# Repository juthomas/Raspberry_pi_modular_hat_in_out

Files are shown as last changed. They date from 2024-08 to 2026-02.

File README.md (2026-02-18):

# Raspberry Pi hat with inputs and outputs for modular synthesizer 

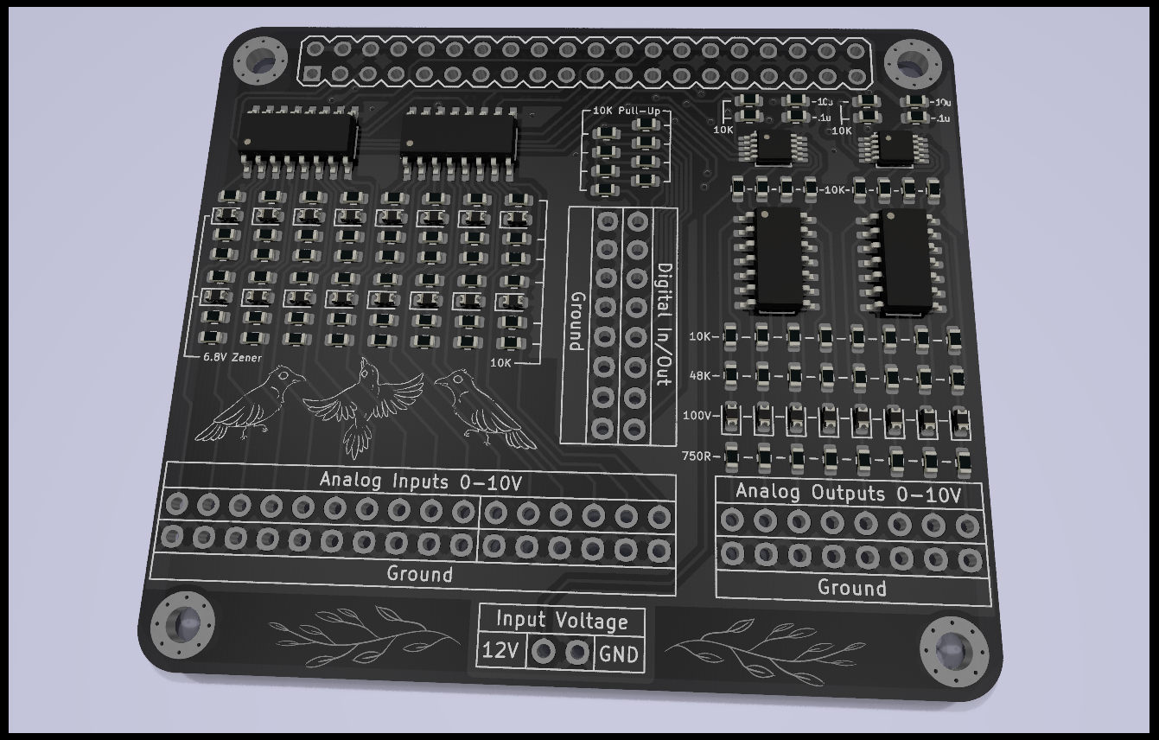
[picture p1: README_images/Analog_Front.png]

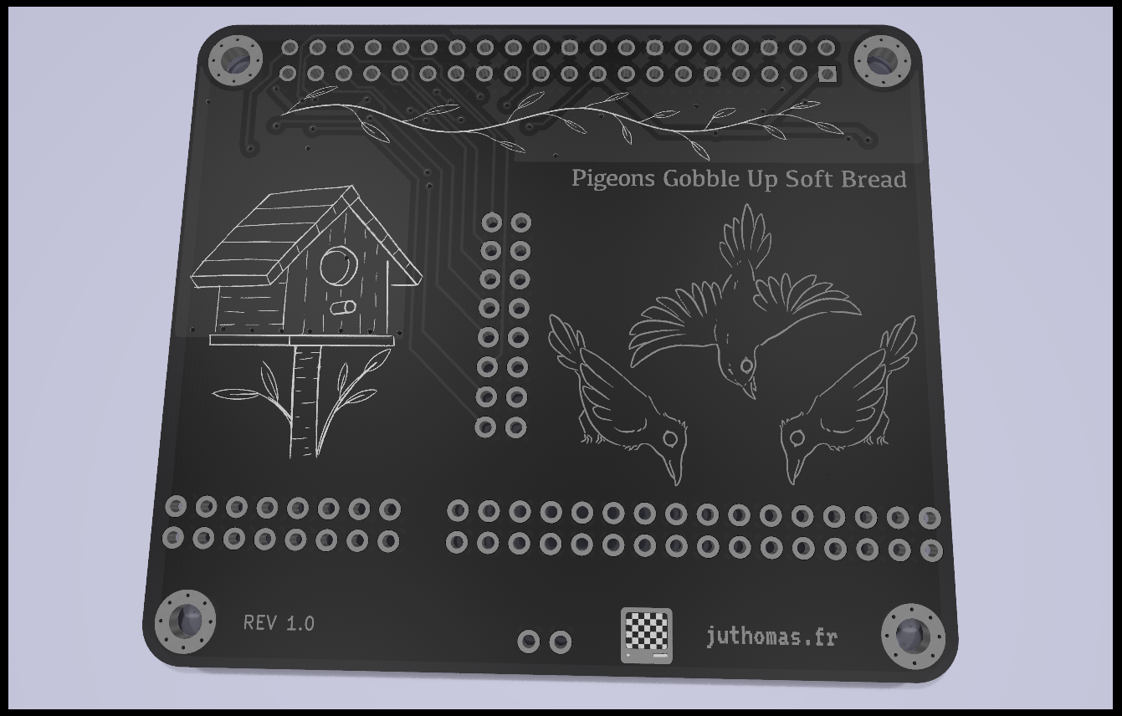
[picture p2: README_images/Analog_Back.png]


## Schematics

- [Link to pdf](https://github.com/juthomas/Raspberry_pi_modular_hat_in_out/blob/master/Schematics%20PDF/Modular_hat_in_out.pdf)

## Bill Of Materials

- [Link to IBOM](https://juthomas.github.io/Raspberry_pi_modular_hat_in_out/)

## Components

- [MCP3008](https://www.lcsc.com/product-detail/Analog-To-Digital-Converters-ADCs_Microchip-Tech-MCP3008-I-SL_C1520159.html) C1520159

- [LM324](https://www.lcsc.com/product-detail/Operational-Amplifier_STMicroelectronics-LM324DT_C71035.html) C71035

- [MCP4728](https://www.lcsc.com/product-detail/Digital-To-Analog-Converters-DACs_Microchip-Tech-MCP4728-E-UN_C108207.html) C108207

## C code examples (clean naming)

- Input reader: `C_code_example/inputs/src/input_reader.c`
  - binary name: `input_reader`
- Output generator: `C_code_example/outputs/src/output_generator.c`
  - binary name: `output_generator`
- Input/Output loopback tester: `C_code_example/input_outputs/src/input_output_tester.c`
  - binary name: `input_output_tester`

## Install dependencies and configure I2C (recommended)

Use the setup script:

`sudo ./scripts/install_rpi_dependencies.sh --baudrate 1000000`

What it does:

- installs apt dependencies (`build-essential`, `cmake`, `git`, `pkg-config`, `libgpiod-dev`, `i2c-tools`)
- installs [spidev-lib](https://github.com/juthomas/spidev-lib) in `/usr/local`
- sets `dtparam=i2c_arm=on,i2c_arm_baudrate=1000000`
- ensures `dtparam=spi=on`
- keeps a backup of `config.txt` before editing

Reboot is required after running the script.

### Manual install (if needed)

`sudo apt install build-essential cmake git pkg-config libgpiod-dev i2c-tools`

`git clone https://github.com/juthomas/spidev-lib.git`

`cd spidev-lib && mkdir -p build && cd build && cmake .. && make -j$(nproc) && sudo make install`

Do not forget to link with `-lspidev-lib` when compiling C code.

## Shell autocompletion for CLI options

The repository includes completion scripts for:

- `output_generator`
- `input_output_tester`
- `install_rpi_dependencies.sh`

Zsh (current session):

`source scripts/completions/rpi_hat_tools.zsh`

Zsh (persistent):

`echo 'source /absolute/path/to/Raspberry_pi_modular_hat_in_out/scripts/completions/rpi_hat_tools.zsh' >> ~/.zshrc`

Bash (current session):

`source scripts/completions/rpi_hat_tools.bash`

Bash (persistent):

`echo 'source /absolute/path/to/Raspberry_pi_modular_hat_in_out/scripts/completions/rpi_hat_tools.bash' >> ~/.bashrc`

## Build and run

Input side (ADC):

`cd C_code_example/inputs && make && ./input_reader`

With runtime options:

`cd C_code_example/inputs && make && ./input_reader --delay-us=100000`

Dashboard cadence is controlled in source with `EQUALIZER_EVERY` and `HISTORY_EVERY` in `C_code_example/inputs/src/input_reader.c`.

Output side (MCP4728):

`cd C_code_example/outputs && make && ./output_generator`

With runtime options:

`cd C_code_example/outputs && make && ./output_generator --resolution=1000 --delay-us=1`

Dashboard cadence is controlled in source with `EQUALIZER_EVERY` and `HISTORY_EVERY` in `C_code_example/outputs/src/output_generator.c`.

Input/Output combined test (MCP4728 sine with per-channel phase + ADS monitoring):

`cd C_code_example/input_outputs && make && ./input_output_tester --resolution=1000 --delay-us=1`

Dashboard cadence is controlled in source with `EQUALIZER_EVERY` and `HISTORY_EVERY` in `C_code_example/input_outputs/src/input_output_tester.c`.

## Electrical Voltage dividers & multiplier

### Divider
https://tinyurl.com/24boqd2k

### Multiplier
<!-- https://tinyurl.com/27d8ra9q -->
https://tinyurl.com/2aczbd22

https://github.com/WiringPi/WiringPi

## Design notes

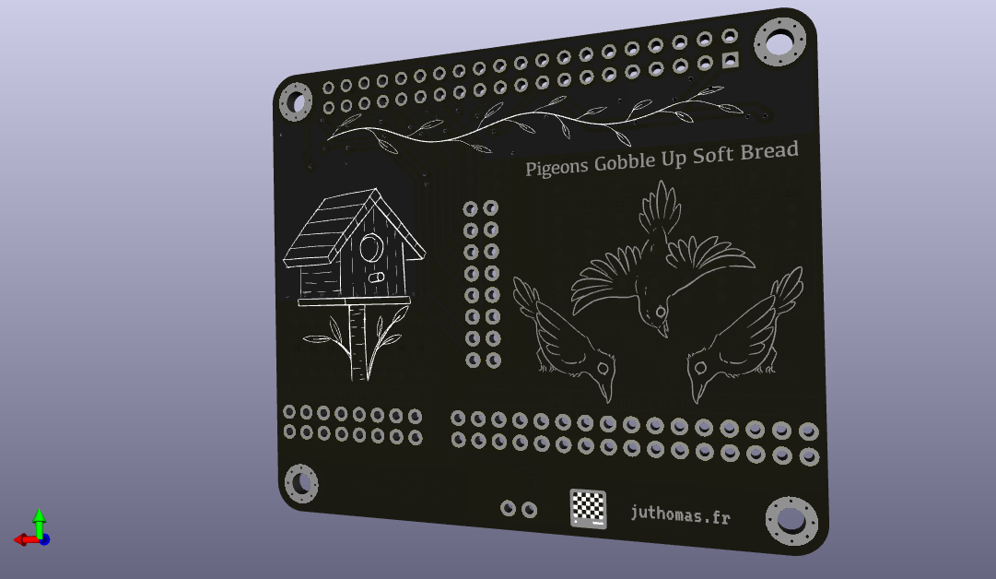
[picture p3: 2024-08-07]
Modular_hat_in_out_kicad/Modular_hat_in_out.png

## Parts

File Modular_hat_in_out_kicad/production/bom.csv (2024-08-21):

Designator | Footprint | Quantity | Value | LCSC Part #
C1, C3 | 0603 | 2 | 0.1uF | C14663
C2, C4 | 0603 | 2 | 10uF | C1691
D1, D10, D11, D12, D13, D14, D15, D16, D2, D3, D4, D5, D6, D7, D8, D9 | 0603 | 16 | D_Zener 6.8V | C2832575
D17, D18, D19, D20, D21, D22, D23, D24 | 0603 | 8 | 300mA 100V | C727112
R1, R10, R11, R12, R13, R14, R15, R16, R17, R18, R19, R2, R20, R21, R22, R23, R24, R25, R26, R27, R28, R29, R3, R30, R31, R32, R33, R34, R35, R36, R37, R38, R39, R4, R40, R41, R42, R43, R44, R45, R46, R47, R48, R49, R5, R50, R51, R52, R53, R54, R55, R56, R57, R58, R6, R61, R62, R64, R65, R67, R68, R7, R73, R74, R75, R77, R78, R79, R8, R80, R82, R84, R85, R86, R87, R9 | 0603 | 76 | 10K | C25804
R59, R60, R63, R66, R76, R81, R83, R88 | 0603 | 8 | 43K | C23172
R69, R70, R71, R72, R89, R90, R91, R92 | 0603 | 8 | 750R | C23241
U1, U3 | MCP3008 SOIC16 | 2 | MCP3008 | C1520159
U2, U6 | LM324 SOIC14 | 2 | LM324 | C71035
U4, U5 | MCP4728 MSOP10 | 2 | MCP4728 | C108207

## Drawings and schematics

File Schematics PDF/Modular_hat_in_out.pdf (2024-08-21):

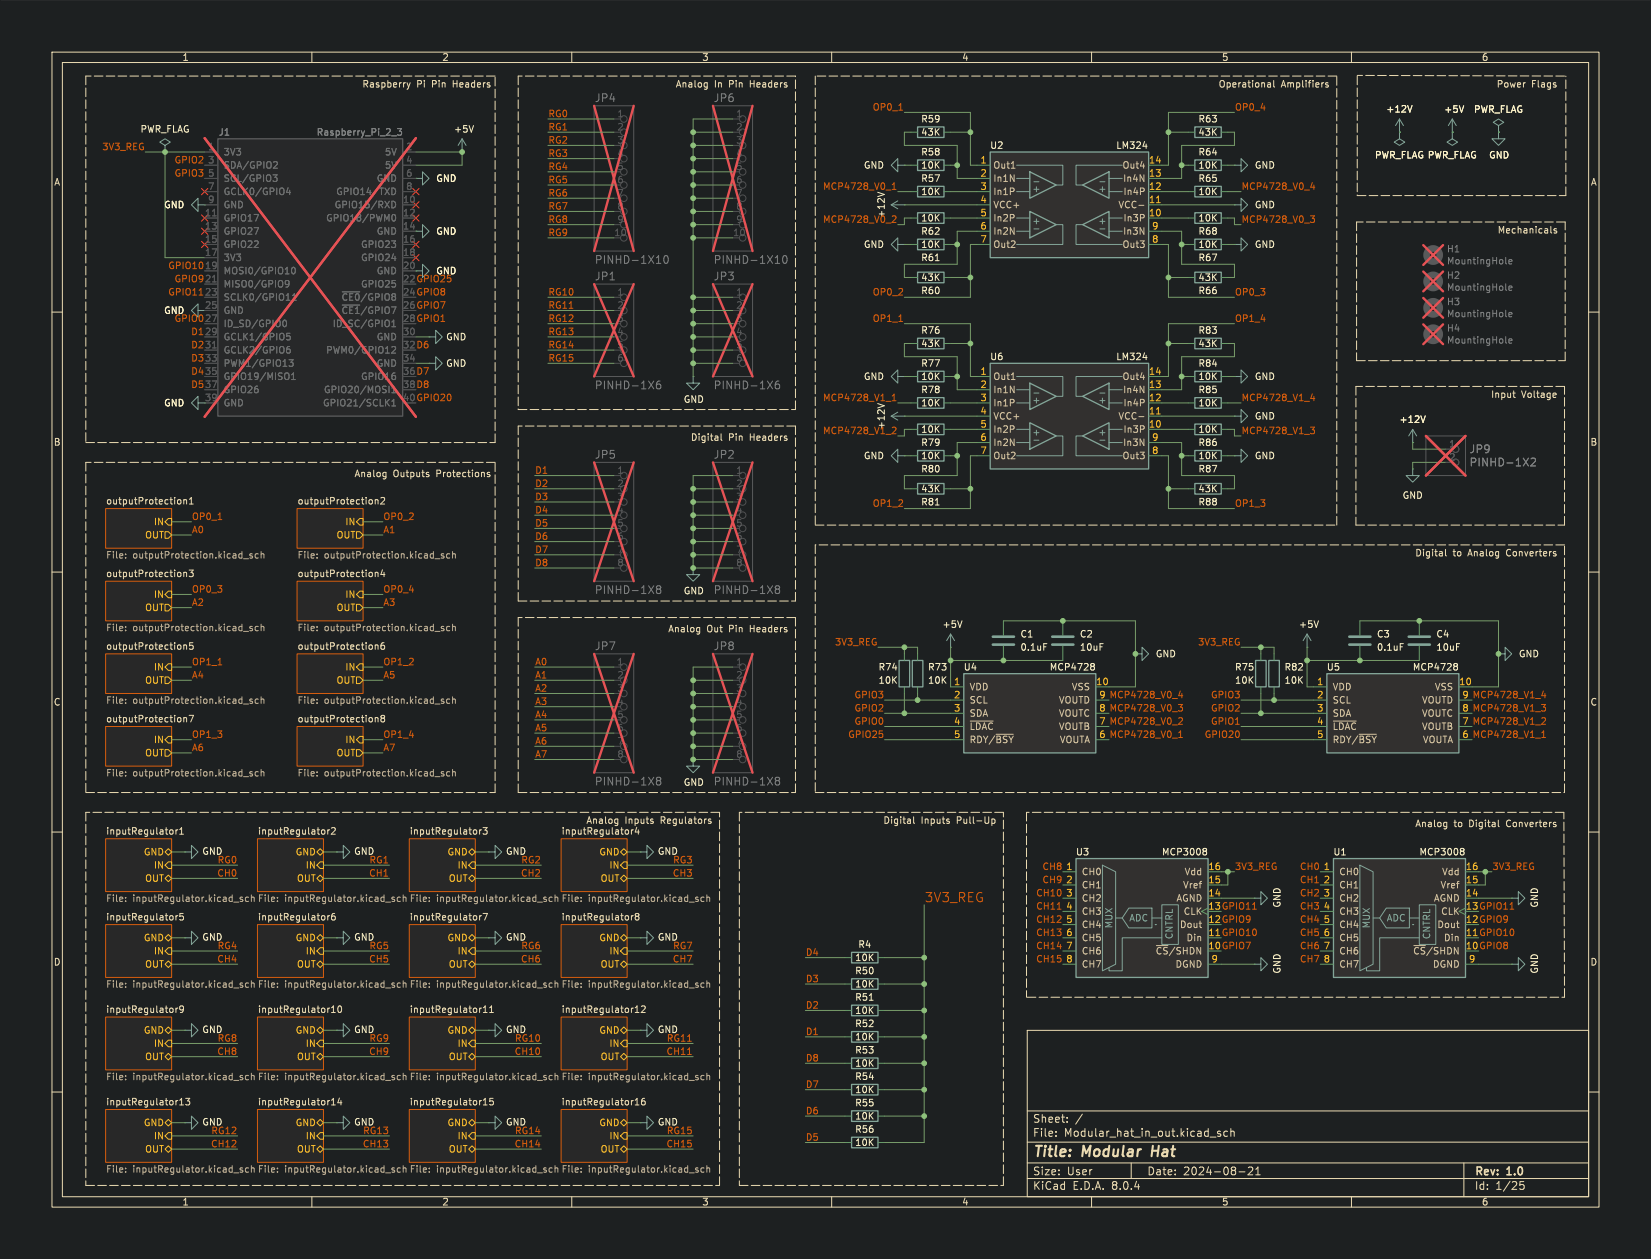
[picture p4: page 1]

Digital Inputs Pull-Up

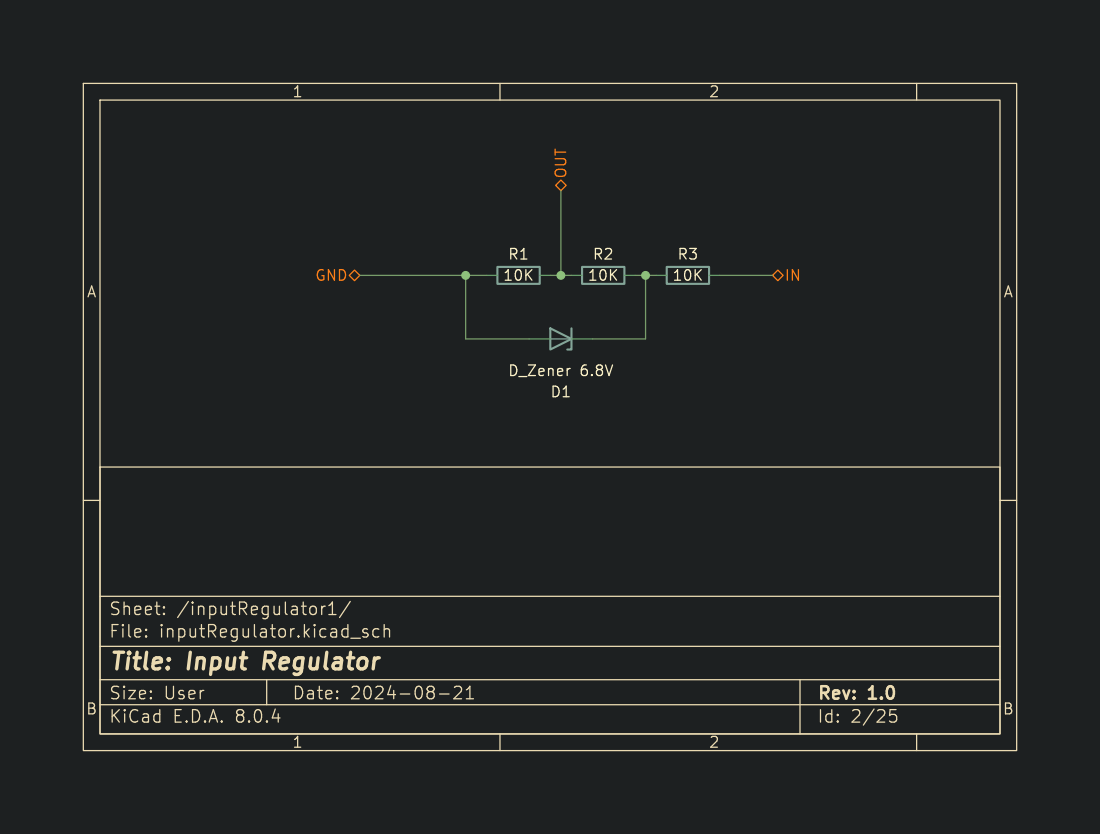
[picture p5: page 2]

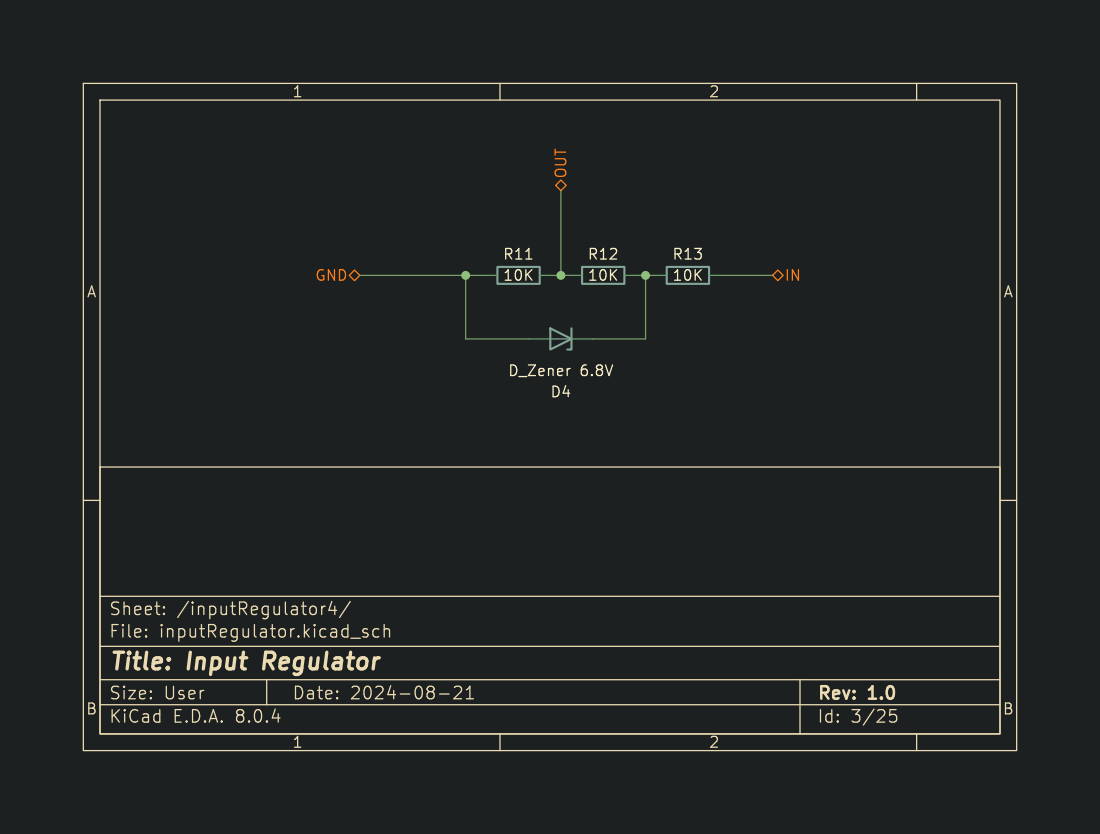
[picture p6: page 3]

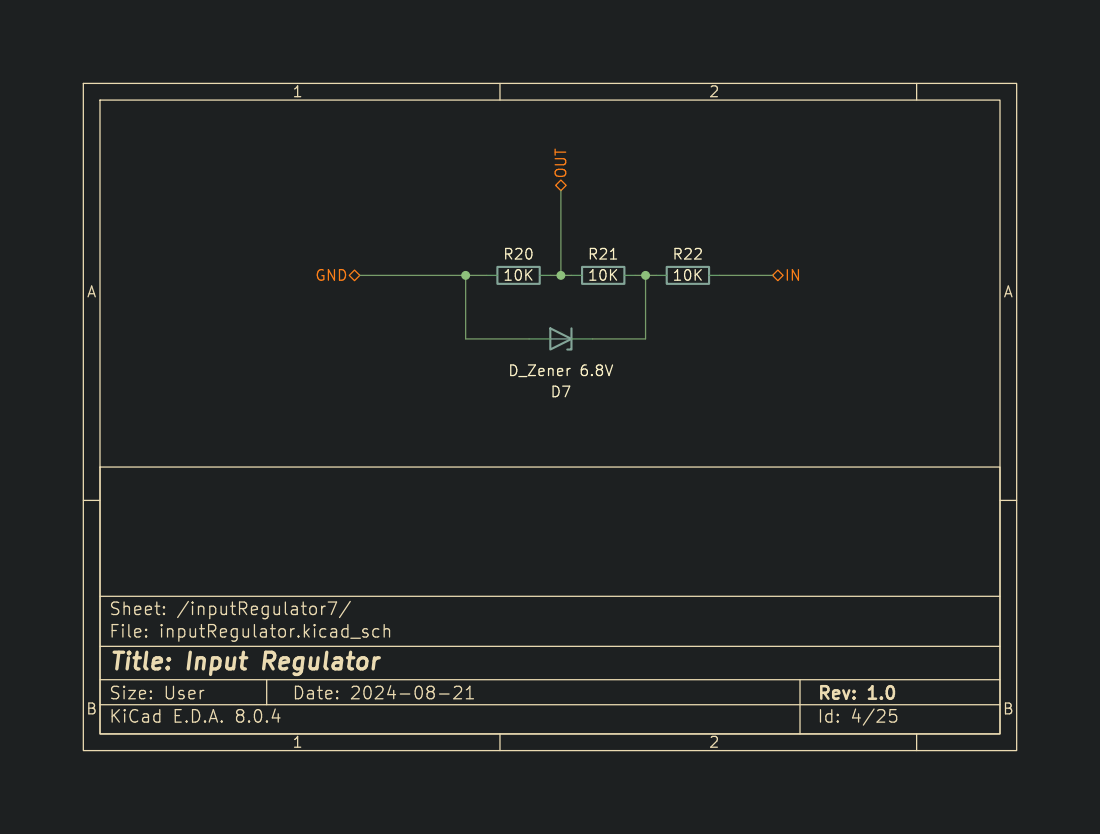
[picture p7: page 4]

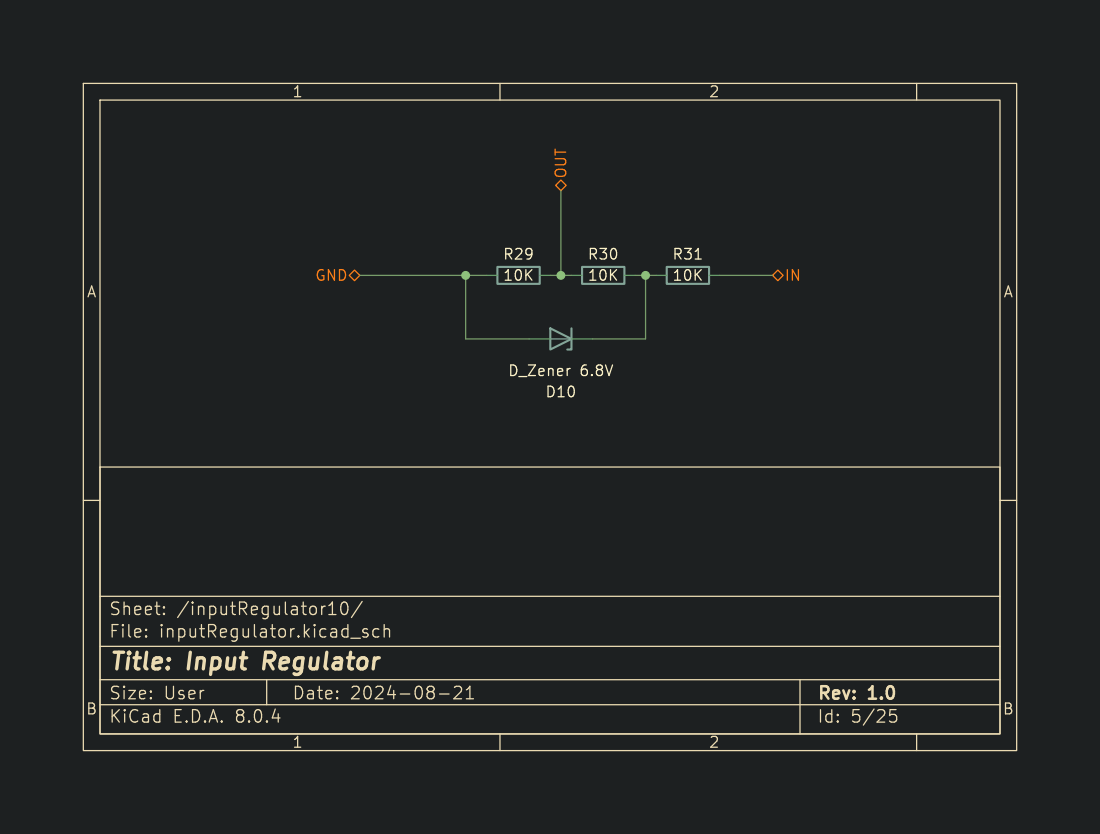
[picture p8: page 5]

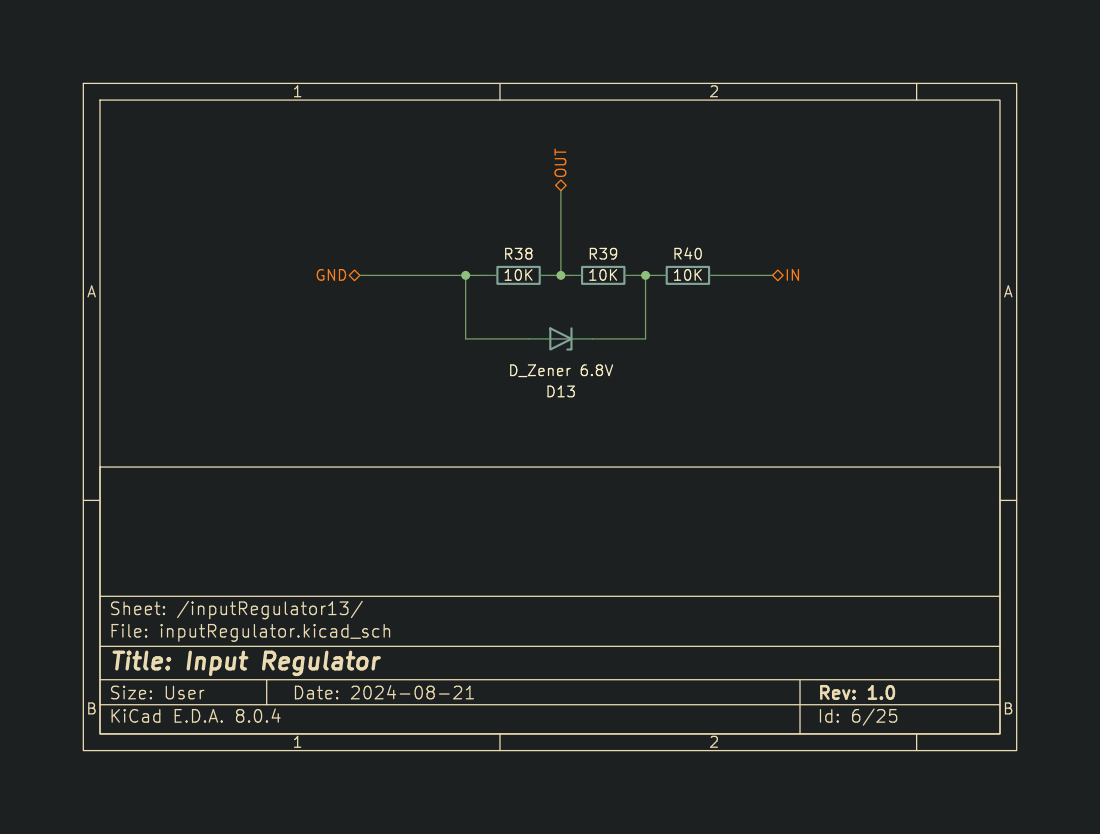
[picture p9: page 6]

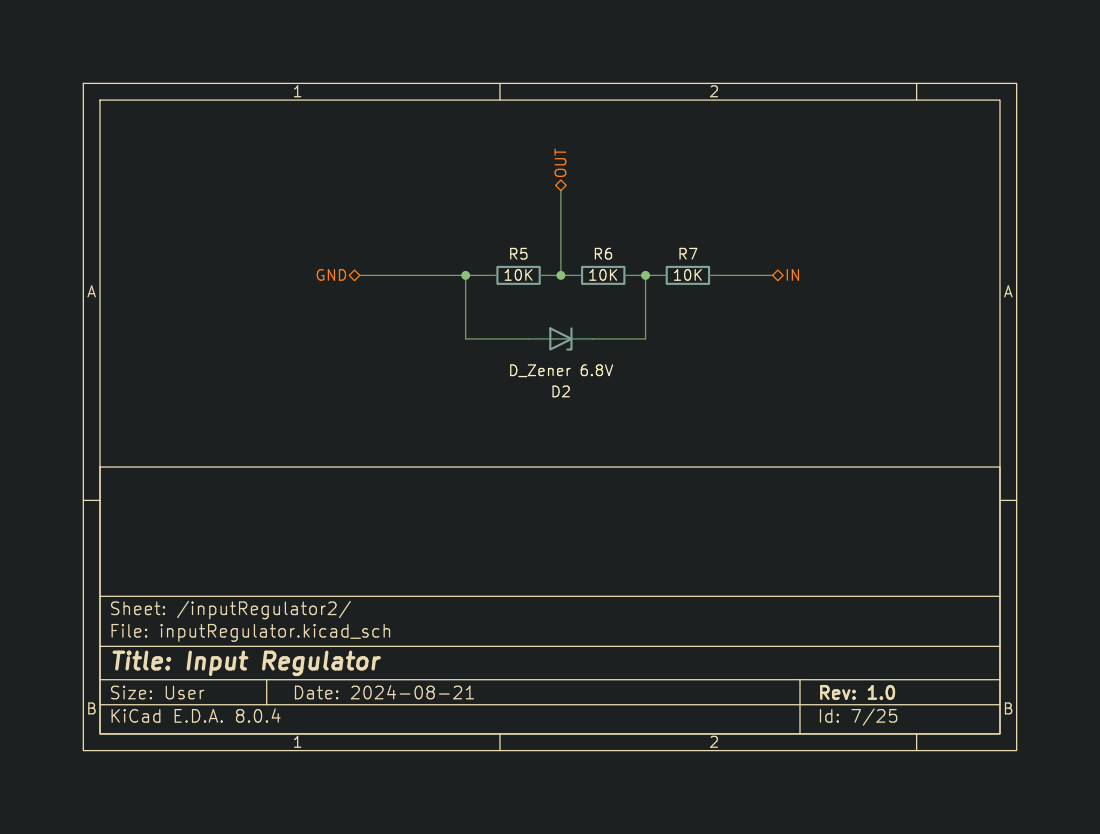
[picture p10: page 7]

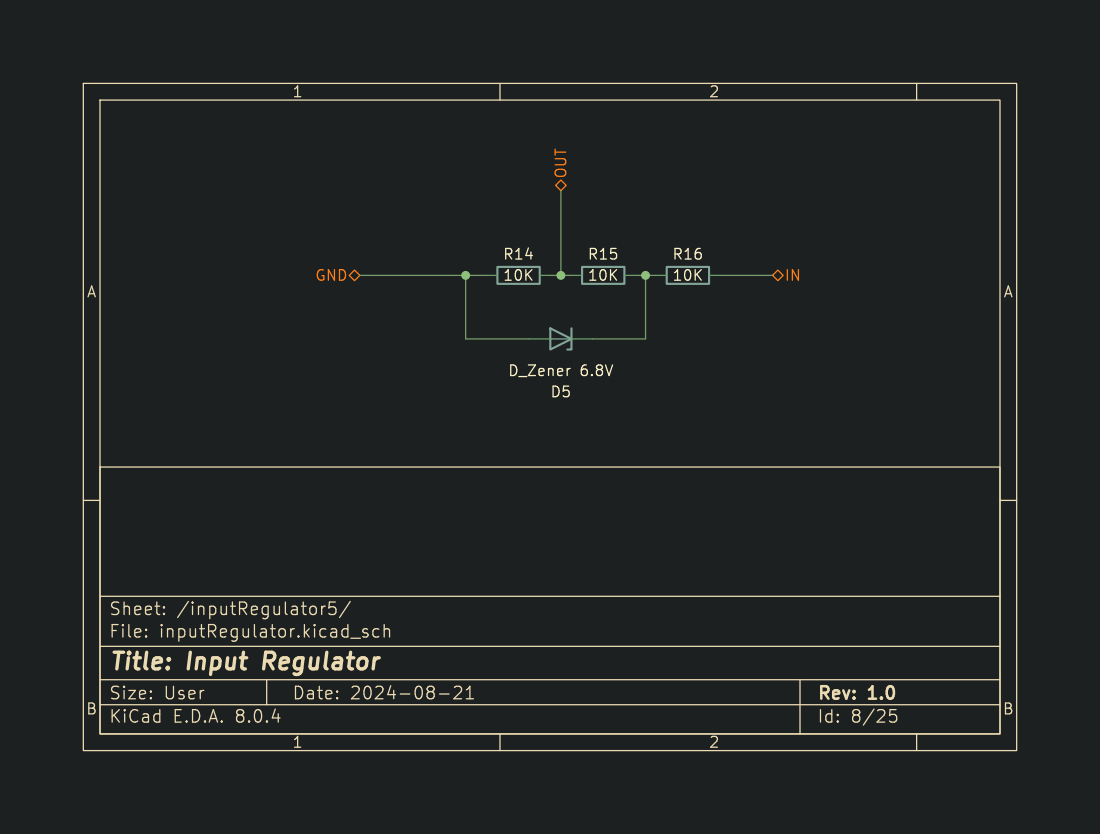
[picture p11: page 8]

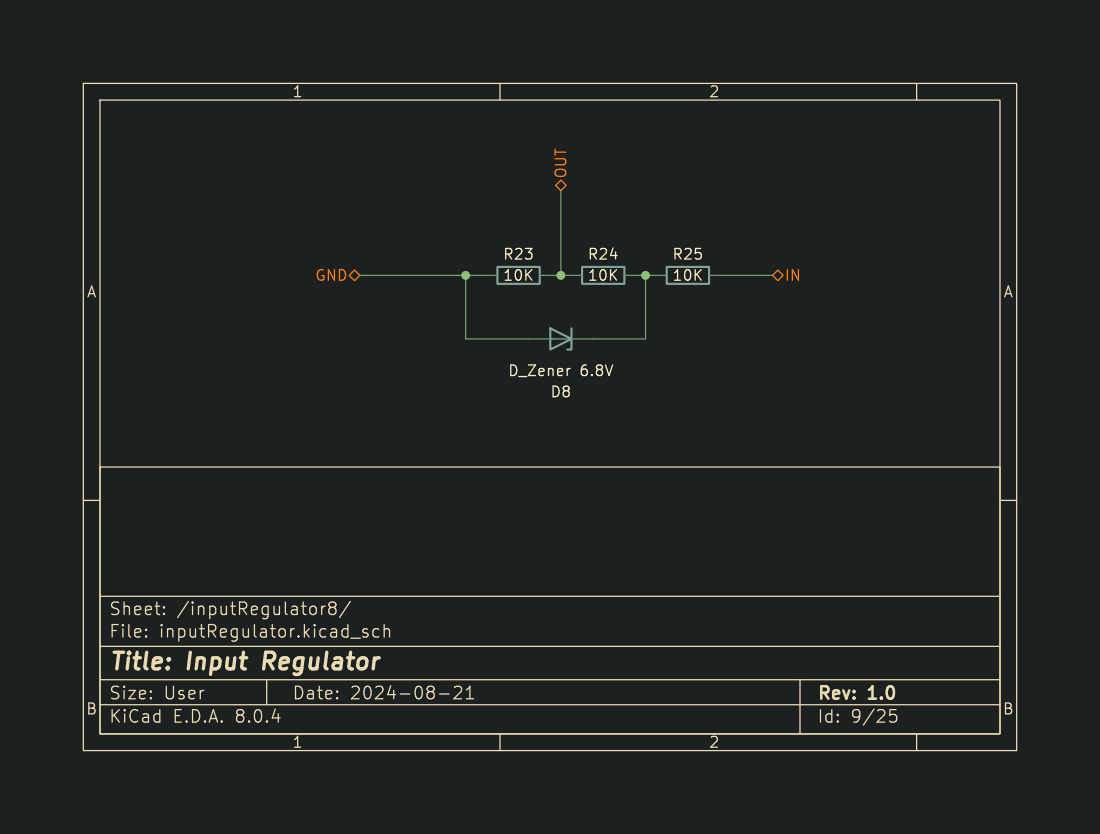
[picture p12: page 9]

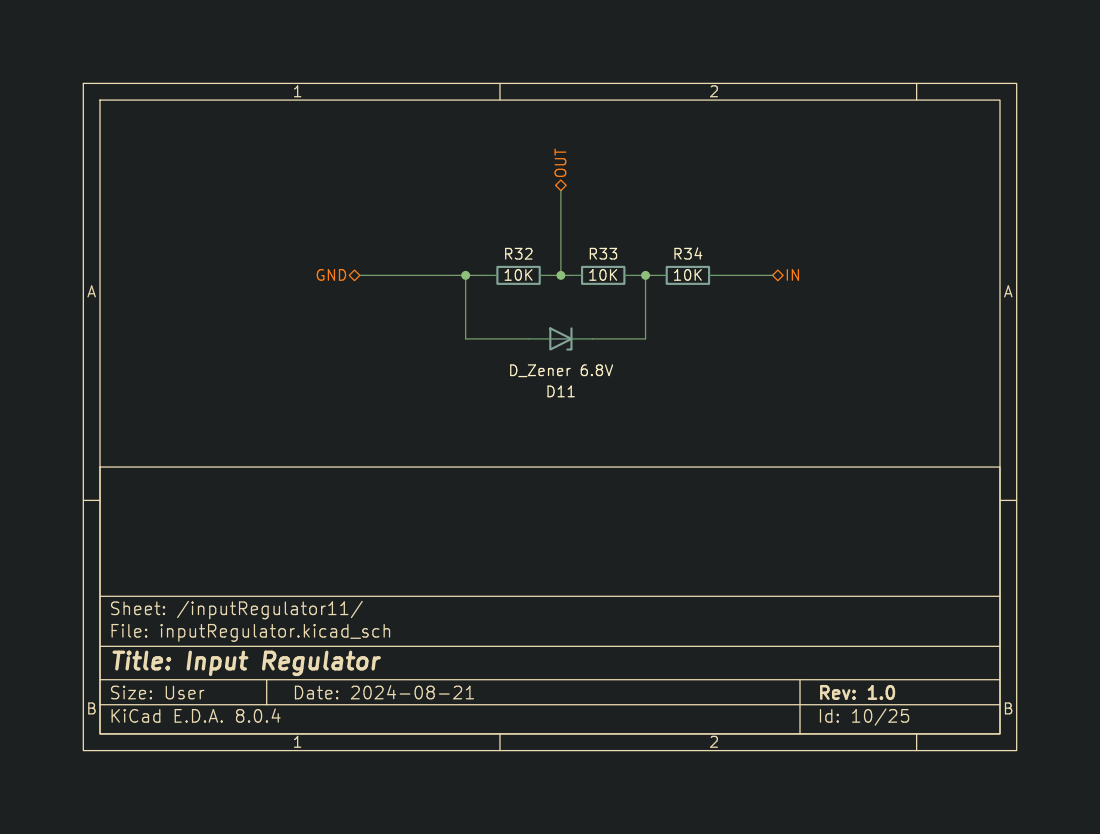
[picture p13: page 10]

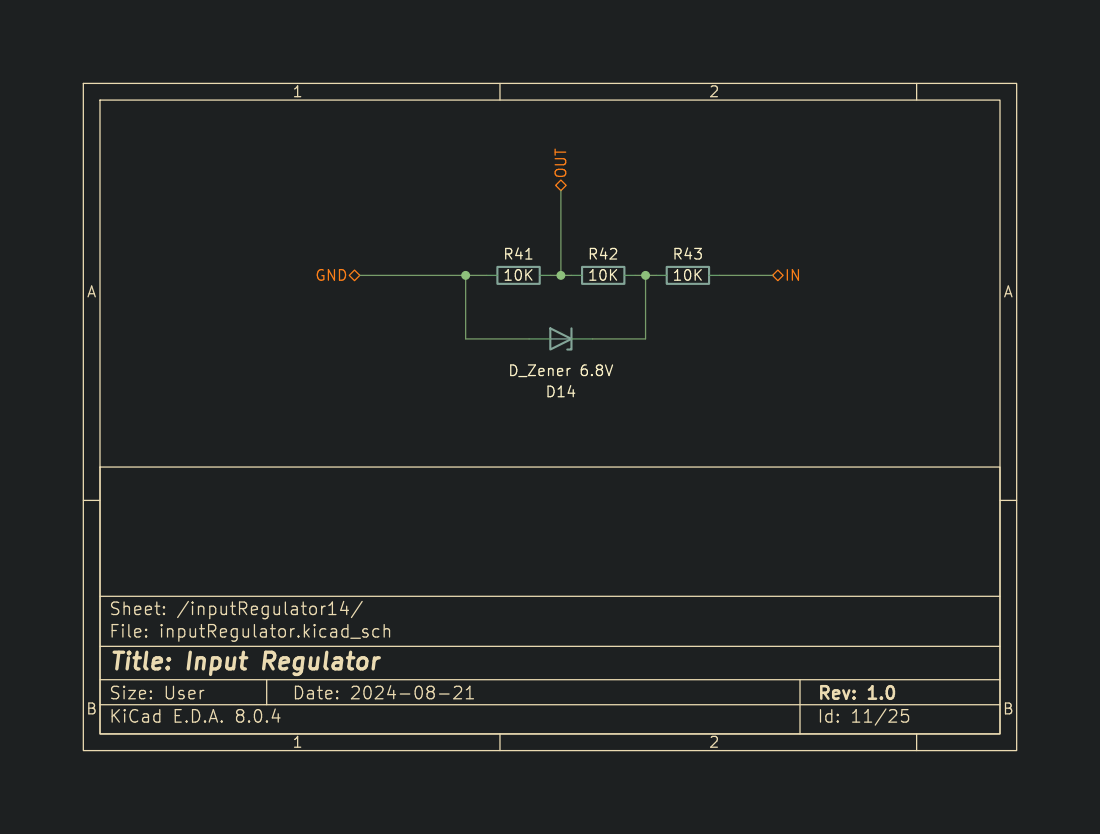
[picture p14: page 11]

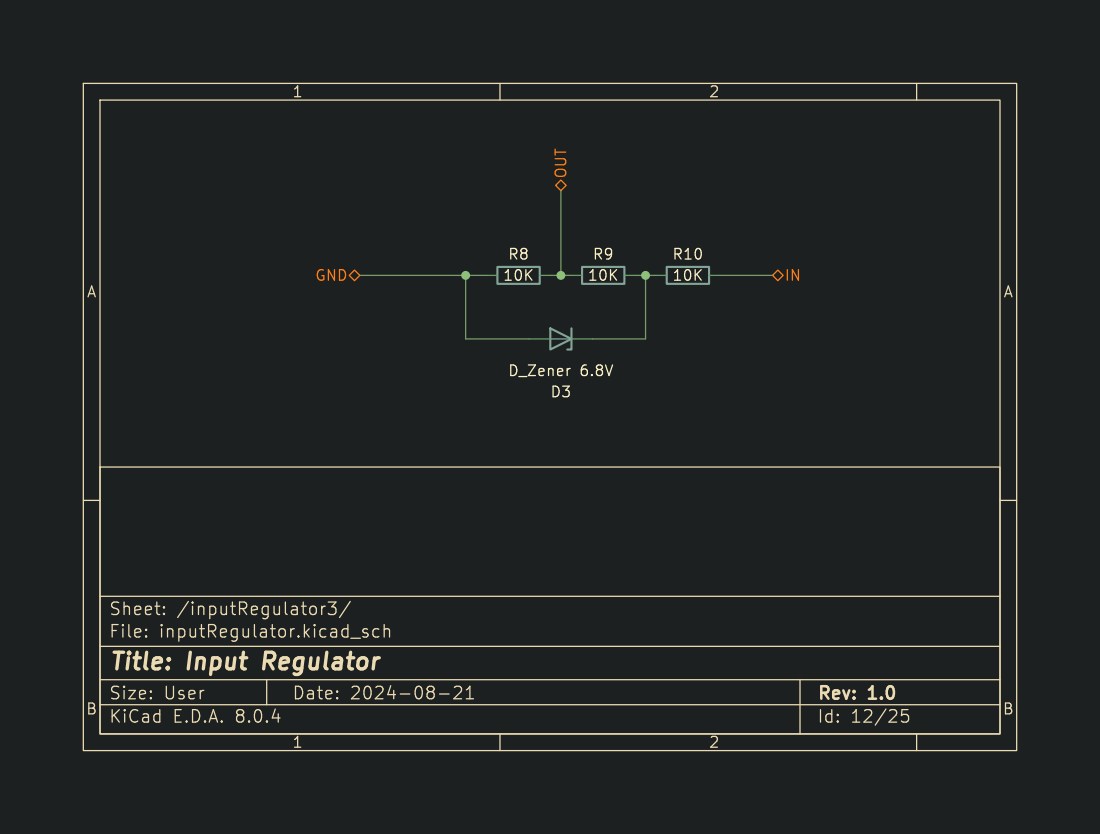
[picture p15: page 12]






Id: 18/25 Title: Output Protection


Id: 19/25 Title: Output Protection


Id: 20/25 Title: Output Protection


Id: 21/25 Title: Output Protection


Id: 22/25 Title: Output Protection


Id: 23/25 Title: Output Protection


Id: 24/25 Title: Output Protection


Id: 25/25 Title: Output Protection

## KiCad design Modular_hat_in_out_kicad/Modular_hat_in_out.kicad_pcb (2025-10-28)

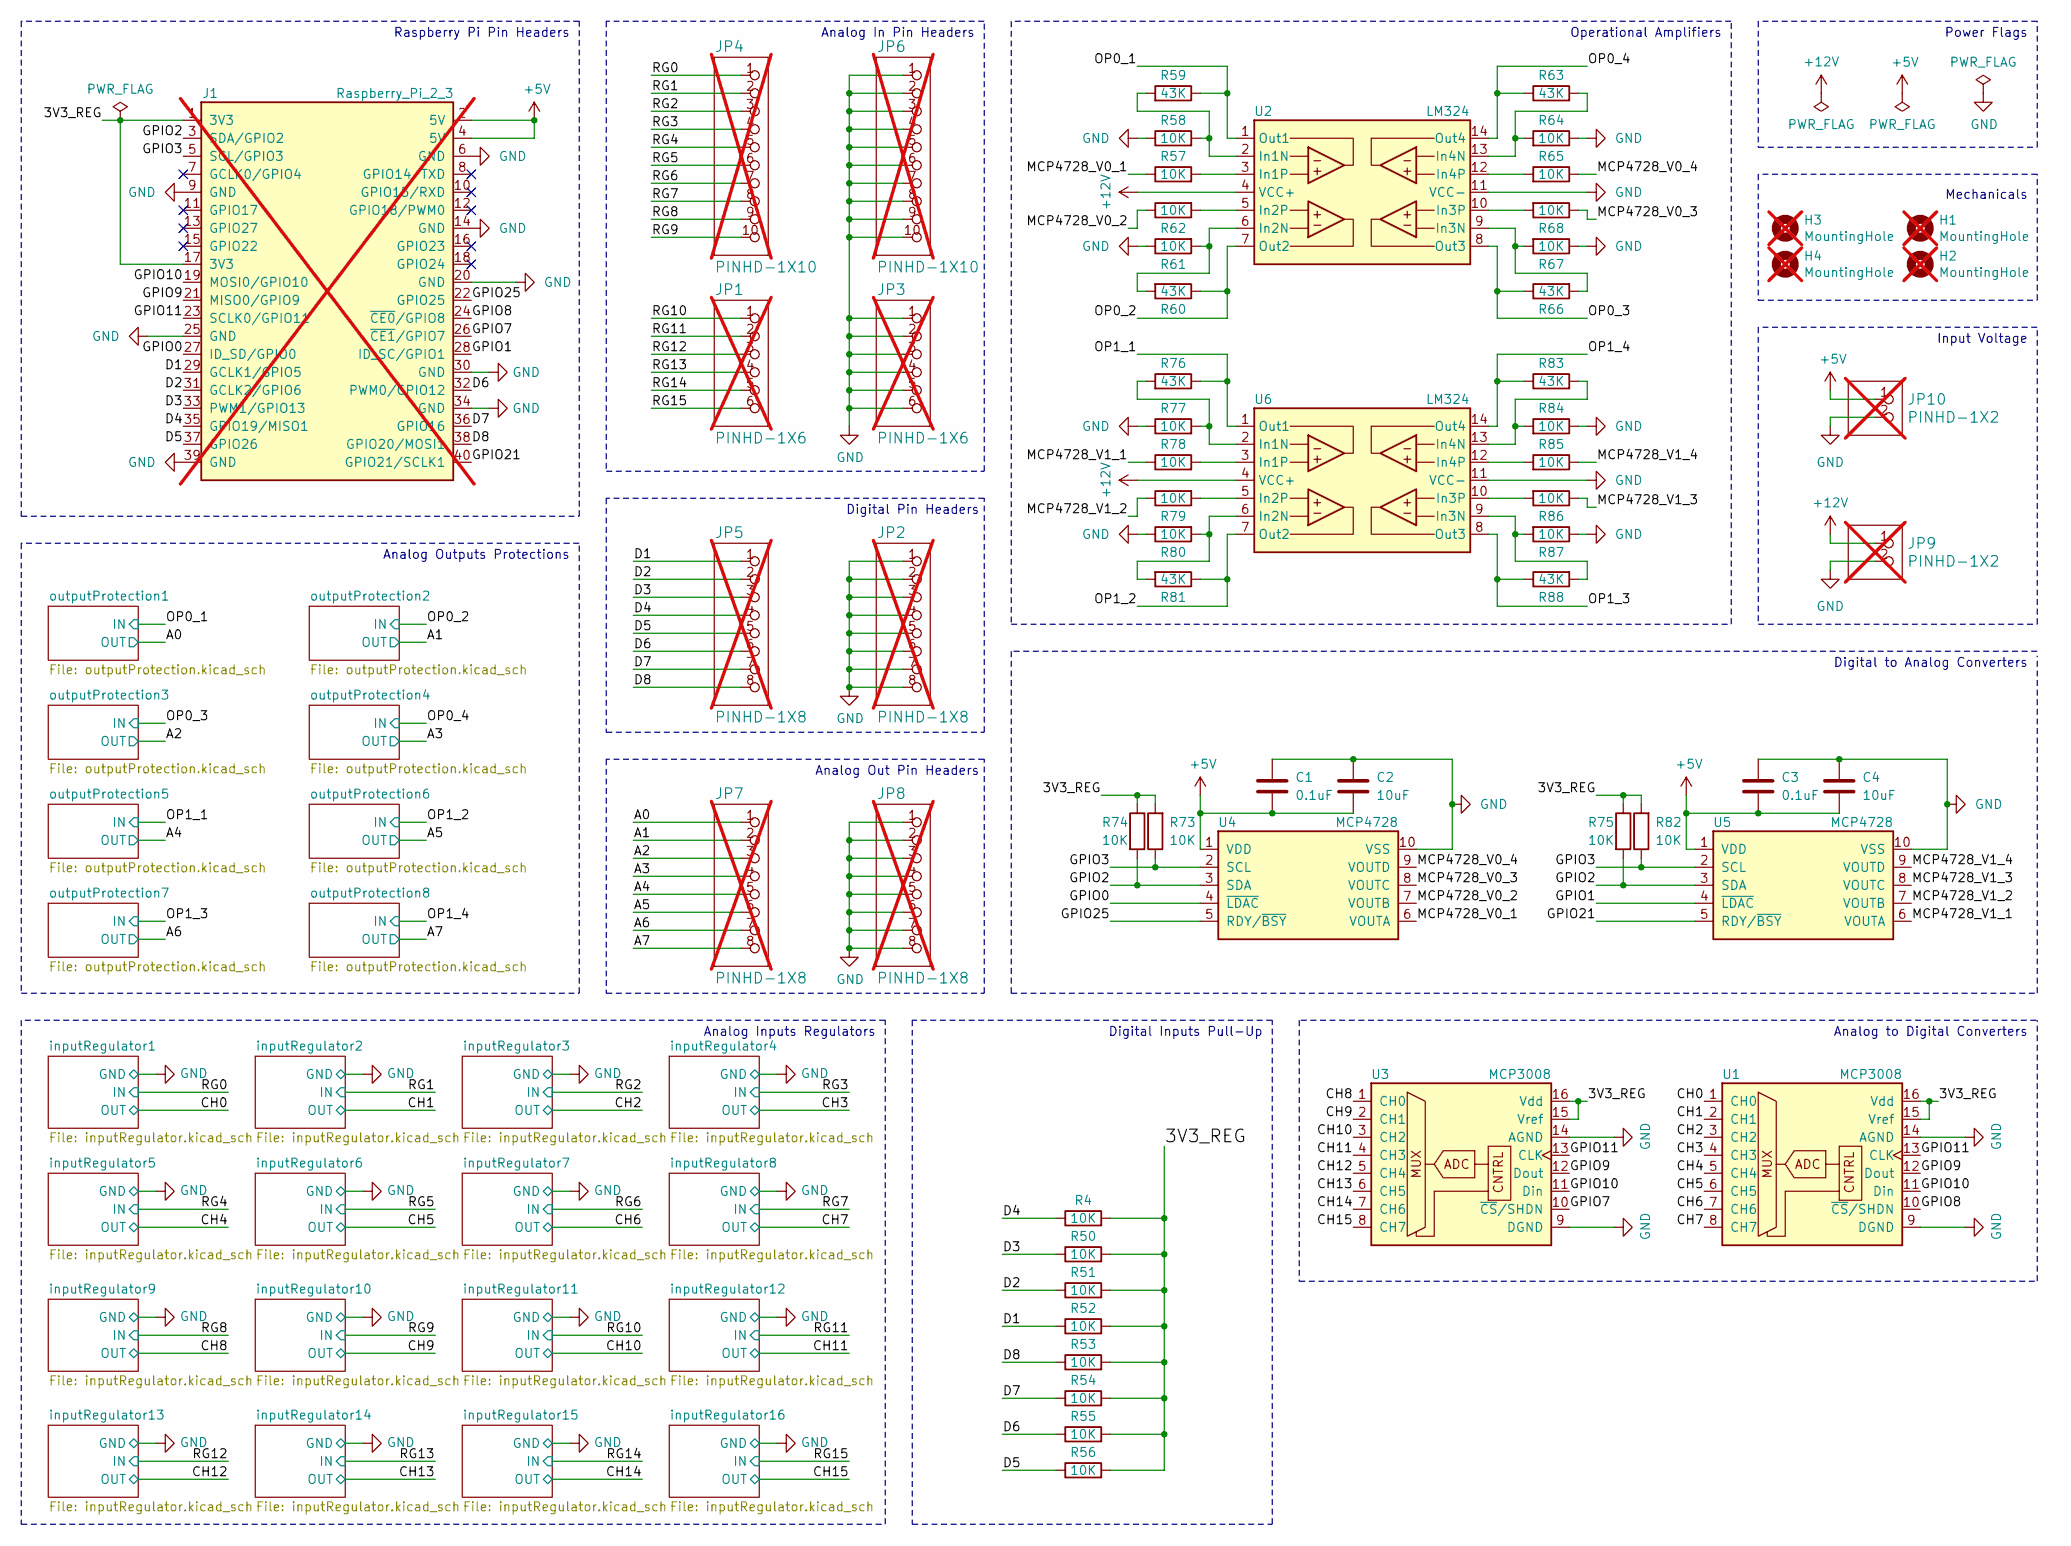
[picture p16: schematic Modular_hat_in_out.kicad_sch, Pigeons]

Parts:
C1, C3: 0.1uF; C_0603_1608Metric; LCSC C14663
C2, C4: 10uF; C_0603_1608Metric; LCSC C1691
H1, H2, H3, H4: MountingHole; MountingHole_2.7mm_M2.5; not fitted
J1: Raspberry_Pi_2_3; PIN_20X2; not fitted
JP1, JP3: PINHD-1X6; 1X06-BIG; not fitted
JP2, JP5, JP7, JP8: PINHD-1X8; 1X08-BIG; not fitted
JP4, JP6: PINHD-1X10; 1X10-BIG; not fitted
JP9, JP10: PINHD-1X2; 1X02-BIG; not fitted
R4, R50, R51, R52, R53, R54, R55, R56, R57, R58, R61, R62, R64, R65, R67, R68, R73, R74, R75, R77, R78, R79, R80, R82, R84, R85, R86, R87: 10K; R_0603_1608Metric; LCSC C25804
R59, R60, R63, R66, R76, R81, R83, R88: 43K; R_0603_1608Metric; LCSC C23172
U1, U3: MCP3008; MCP3008 SOIC16; LCSC C1520159
U2, U6: LM324; LM324 SOIC14; LCSC C71035
U4, U5: MCP4728; MCP4728 MSOP10; LCSC C108207

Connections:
+5V: C1.1, C2.1, C3.1, C4.1, J1.2 (5V), J1.4 (5V), JP10.1, U4.1 (VDD), U5.1 (VDD)
+12V: JP9.1, U2.4 (VCC+), U6.4 (VCC+)
/3V3_REG: J1.1 (3V3), J1.17 (3V3), R4.2, R50.2, R51.2, R52.2, R53.2, R54.2, R55.2, R56.2, R73.2, R74.1, R75.1, R82.2, U1.15 (Vref), U1.16 (Vdd), U3.15 (Vref), U3.16 (Vdd)
/A0: JP7.1; also elsewhere on the board
/A1: JP7.2; also elsewhere on the board
/A2: JP7.3; also elsewhere on the board
/A3: JP7.4; also elsewhere on the board
/A4: JP7.5; also elsewhere on the board
/A5: JP7.6; also elsewhere on the board
/A6: JP7.7; also elsewhere on the board
/A7: JP7.8; also elsewhere on the board
/CH0: U1.1 (CH0); also elsewhere on the board
/CH1: U1.2 (CH1); also elsewhere on the board
/CH2: U1.3 (CH2); also elsewhere on the board
/CH3: U1.4 (CH3); also elsewhere on the board
/CH4: U1.5 (CH4); also elsewhere on the board
/CH5: U1.6 (CH5); also elsewhere on the board
/CH6: U1.7 (CH6); also elsewhere on the board
/CH7: U1.8 (CH7); also elsewhere on the board
/CH8: U3.1 (CH0); also elsewhere on the board
/CH9: U3.2 (CH1); also elsewhere on the board
/CH10: U3.3 (CH2); also elsewhere on the board
/CH11: U3.4 (CH3); also elsewhere on the board
/CH12: U3.5 (CH4); also elsewhere on the board
/CH13: U3.6 (CH5); also elsewhere on the board
/CH14: U3.7 (CH6); also elsewhere on the board
/CH15: U3.8 (CH7); also elsewhere on the board
/D1: J1.29 (GCLK1/GPIO5), JP5.1, R52.1
/D2: J1.31 (GCLK2/GPIO6), JP5.2, R51.1
/D3: J1.33 (PWM1/GPIO13), JP5.3, R50.1
/D4: J1.35 (GPIO19/MISO1), JP5.4, R4.1
/D5: J1.37 (GPIO26), JP5.5, R56.1
/D6: J1.32 (PWM0/GPIO12), JP5.6, R55.1
/D7: J1.36 (GPIO16), JP5.7, R54.1
/D8: J1.38 (GPIO20/MOSI1), JP5.8, R53.1
/GPIO0: J1.27 (ID_SD/GPIO0), U4.4 (~LDAC)
/GPIO1: J1.28 (ID_SC/GPIO1), U5.4 (~LDAC)
/GPIO2: J1.3 (SDA/GPIO2), R74.2, R75.2, U4.3 (SDA), U5.3 (SDA)
/GPIO3: J1.5 (SCL/GPIO3), R73.1, R82.1, U4.2 (SCL), U5.2 (SCL)
/GPIO7: J1.26 (~CE1/GPIO7), U3.10 (~CS/SHDN)
/GPIO8: J1.24 (~CE0/GPIO8), U1.10 (~CS/SHDN)
/GPIO9: J1.21 (MISO0/GPIO9), U1.12 (Dout), U3.12 (Dout)
/GPIO10: J1.19 (MOSI0/GPIO10), U1.11 (Din), U3.11 (Din)
/GPIO11: J1.23 (SCLK0/GPIO11), U1.13 (CLK), U3.13 (CLK)
/GPIO21: J1.40 (GPIO21/SCLK1), U5.5 (RDY/~BSY)
/GPIO25: J1.22 (GPIO25), U4.5 (RDY/~BSY)
/MCP4728_V0_1: R57.1, U4.6 (VOUTA)
/MCP4728_V0_2: R62.1, U4.7 (VOUTB)
/MCP4728_V0_3: R68.1, U4.8 (VOUTC)
/MCP4728_V0_4: R65.1, U4.9 (VOUTD)
/MCP4728_V1_1: R78.1, U5.6 (VOUTA)
/MCP4728_V1_2: R79.1, U5.7 (VOUTB)
/MCP4728_V1_3: R86.1, U5.8 (VOUTC)
/MCP4728_V1_4: R85.1, U5.9 (VOUTD)
/OP0_1: R59.2, U2.1 (Out1); also elsewhere on the board
/OP0_2: R60.2, U2.7 (Out2); also elsewhere on the board
/OP0_3: R66.2, U2.8 (Out3); also elsewhere on the board
/OP0_4: R63.2, U2.14 (Out4); also elsewhere on the board
/OP1_1: R76.2, U6.1 (Out1); also elsewhere on the board
/OP1_2: R81.2, U6.7 (Out2); also elsewhere on the board
/OP1_3: R88.2, U6.8 (Out3); also elsewhere on the board
/OP1_4: R83.2, U6.14 (Out4); also elsewhere on the board
/RG0: JP4.1; also elsewhere on the board
/RG1: JP4.2; also elsewhere on the board
/RG2: JP4.3; also elsewhere on the board
/RG3: JP4.4; also elsewhere on the board
/RG4: JP4.5; also elsewhere on the board
/RG5: JP4.6; also elsewhere on the board
/RG6: JP4.7; also elsewhere on the board
/RG7: JP4.8; also elsewhere on the board
/RG8: JP4.9; also elsewhere on the board
/RG9: JP4.10; also elsewhere on the board
/RG10: JP1.1; also elsewhere on the board
/RG11: JP1.2; also elsewhere on the board
/RG12: JP1.3; also elsewhere on the board
/RG13: JP1.4; also elsewhere on the board
/RG14: JP1.5; also elsewhere on the board
/RG15: JP1.6; also elsewhere on the board
GND: C1.2, C2.2, C3.2, C4.2, J1.6 (GND), J1.9 (GND), J1.14 (GND), J1.20 (GND), J1.25 (GND), J1.30 (GND), J1.34 (GND), J1.39 (GND), JP2.1, JP2.2, JP2.3, JP2.4, JP2.5, JP2.6, JP2.7, JP2.8, JP3.1, JP3.2, JP3.3, JP3.4, JP3.5, JP3.6, JP6.1, JP6.2, JP6.3, JP6.4, JP6.5, JP6.6, JP6.7, JP6.8, JP6.9, JP6.10, JP8.1, JP8.2, JP8.3, JP8.4, JP8.5, JP8.6, JP8.7, JP8.8, JP9.2, JP10.2, R58.1, R61.1, R64.1, R67.1, R77.1, R80.1, R84.1, R87.1, U1.9 (DGND), U1.14 (AGND), U2.11 (VCC-), U3.9 (DGND), U3.14 (AGND), U4.10 (VSS), U5.10 (VSS), U6.11 (VCC-); also elsewhere on the board
unnamed: R58.2, R59.1, U2.2 (In1N)
unnamed: R57.2, U2.3 (In1P)
unnamed: R60.1, R61.2, U2.6 (In2N)
unnamed: R62.2, U2.5 (In2P)
unnamed: R66.1, R67.2, U2.9 (In3N)
unnamed: R68.2, U2.10 (In3P)
unnamed: R63.1, R64.2, U2.13 (In4N)
unnamed: R65.2, U2.12 (In4P)
unnamed: R76.1, R77.2, U6.2 (In1N)
unnamed: R78.2, U6.3 (In1P)
unnamed: R80.2, R81.1, U6.6 (In2N)
unnamed: R79.2, U6.5 (In2P)
unnamed: R87.2, R88.1, U6.9 (In3N)
unnamed: R86.2, U6.10 (In3P)
unnamed: R83.1, R84.2, U6.13 (In4N)
unnamed: R85.2, U6.12 (In4P)

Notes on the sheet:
Analog Outputs Protections
Digital Inputs Pull-Up
Analog Out Pin Headers
Raspberry Pi Pin Headers
Operational Amplifiers
Input Voltage
Mechanicals
Analog Inputs Regulators
Digital Pin Headers
Digital to Analog Converters
Analog In Pin Headers
Analog to Digital Converters
Power Flags

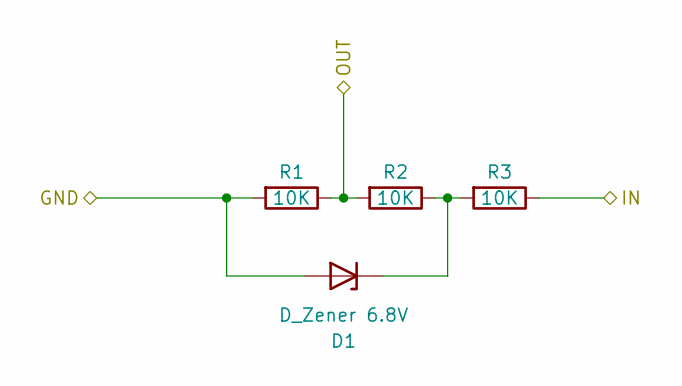
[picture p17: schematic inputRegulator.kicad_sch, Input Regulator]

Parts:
D1: D_Zener 6.8V; D_Z_0603_1608Metric; LCSC C2832575
R1, R2, R3: 10K; R_0603_1608Metric; LCSC C25804

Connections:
/CH0: R1.1, R2.2; also elsewhere on the board
/RG0: R3.1; also elsewhere on the board
GND: D1.2 (A), R1.2; also elsewhere on the board
unnamed: D1.1 (K), R2.1, R3.2

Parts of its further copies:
D2, D3, D4, D5, D6, D7, D8, D9, D10, D11, D12, D13, D14, D15, D16: D_Zener 6.8V; D_Z_0603_1608Metric; LCSC C2832575
R5, R6, R7, R8, R9, R10, R11, R12, R13, R14, R15, R16, R17, R18, R19, R20, R21, R22, R23, R24, R25, R26, R27, R28, R29, R30, R31, R32, R33, R34, R35, R36, R37, R38, R39, R40, R41, R42, R43, R44, R45, R46, R47, R48, R49: 10K; R_0603_1608Metric; LCSC C25804

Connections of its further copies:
/CH1: R5.1, R6.2; also elsewhere on the board
/CH2: R8.1, R9.2; also elsewhere on the board
/CH3: R11.1, R12.2; also elsewhere on the board
/CH4: R14.1, R15.2; also elsewhere on the board
/CH5: R17.1, R18.2; also elsewhere on the board
/CH6: R20.1, R21.2; also elsewhere on the board
/CH7: R23.1, R24.2; also elsewhere on the board
/CH8: R26.1, R27.2; also elsewhere on the board
/CH9: R29.1, R30.2; also elsewhere on the board
/CH10: R32.1, R33.2; also elsewhere on the board
/CH11: R35.1, R36.2; also elsewhere on the board
/CH12: R38.1, R39.2; also elsewhere on the board
/CH13: R41.1, R42.2; also elsewhere on the board
/CH14: R44.1, R45.2; also elsewhere on the board
/CH15: R47.1, R48.2; also elsewhere on the board
/RG1: R7.1; also elsewhere on the board
/RG2: R10.1; also elsewhere on the board
/RG3: R13.1; also elsewhere on the board
/RG4: R16.1; also elsewhere on the board
/RG5: R19.1; also elsewhere on the board
/RG6: R22.1; also elsewhere on the board
/RG7: R25.1; also elsewhere on the board
/RG8: R28.1; also elsewhere on the board
/RG9: R31.1; also elsewhere on the board
/RG10: R34.1; also elsewhere on the board
/RG11: R37.1; also elsewhere on the board
/RG12: R40.1; also elsewhere on the board
/RG13: R43.1; also elsewhere on the board
/RG14: R46.1; also elsewhere on the board
/RG15: R49.1; also elsewhere on the board
GND: D2.2 (A), D3.2 (A), D4.2 (A), D5.2 (A), D6.2 (A), D7.2 (A), D8.2 (A), D9.2 (A), D10.2 (A), D11.2 (A), D12.2 (A), D13.2 (A), D14.2 (A), D15.2 (A), D16.2 (A), R5.2, R8.2, R11.2, R14.2, R17.2, R20.2, R23.2, R26.2, R29.2, R32.2, R35.2, R38.2, R41.2, R44.2, R47.2; also elsewhere on the board
unnamed: D2.1 (K), R6.1, R7.2
unnamed: D3.1 (K), R9.1, R10.2
unnamed: D4.1 (K), R12.1, R13.2
unnamed: D5.1 (K), R15.1, R16.2
unnamed: D6.1 (K), R18.1, R19.2
unnamed: D7.1 (K), R21.1, R22.2
unnamed: D8.1 (K), R24.1, R25.2
unnamed: D9.1 (K), R27.1, R28.2
unnamed: D10.1 (K), R30.1, R31.2
unnamed: D11.1 (K), R33.1, R34.2
unnamed: D12.1 (K), R36.1, R37.2
unnamed: D13.1 (K), R39.1, R40.2
unnamed: D14.1 (K), R42.1, R43.2
unnamed: D15.1 (K), R45.1, R46.2
unnamed: D16.1 (K), R48.1, R49.2

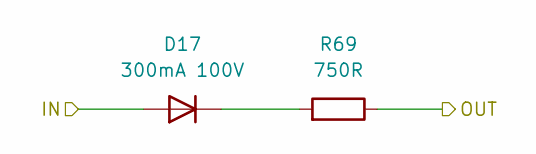
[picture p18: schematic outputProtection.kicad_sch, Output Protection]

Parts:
D17: 300mA 100V; D_0603_1608Metric; LCSC C727112
R69: 750R; R_0603_1608Metric; LCSC C23241

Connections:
/A0: R69.2; also elsewhere on the board
/OP0_1: D17.2 (A); also elsewhere on the board
unnamed: D17.1 (K), R69.1

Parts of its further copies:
D18, D19, D20, D21, D22, D23, D24: 300mA 100V; D_0603_1608Metric; LCSC C727112
R70, R71, R72, R89, R90, R91, R92: 750R; R_0603_1608Metric; LCSC C23241

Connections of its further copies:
/A1: R70.2; also elsewhere on the board
/A2: R71.2; also elsewhere on the board
/A3: R72.2; also elsewhere on the board
/A4: R89.2; also elsewhere on the board
/A5: R90.2; also elsewhere on the board
/A6: R91.2; also elsewhere on the board
/A7: R92.2; also elsewhere on the board
/OP0_2: D18.2 (A); also elsewhere on the board
/OP0_3: D19.2 (A); also elsewhere on the board
/OP0_4: D20.2 (A); also elsewhere on the board
/OP1_1: D21.2 (A); also elsewhere on the board
/OP1_2: D22.2 (A); also elsewhere on the board
/OP1_3: D23.2 (A); also elsewhere on the board
/OP1_4: D24.2 (A); also elsewhere on the board
unnamed: D18.1 (K), R70.1
unnamed: D19.1 (K), R71.1
unnamed: D20.1 (K), R72.1
unnamed: D21.1 (K), R89.1
unnamed: D22.1 (K), R90.1
unnamed: D23.1 (K), R91.1
unnamed: D24.1 (K), R92.1

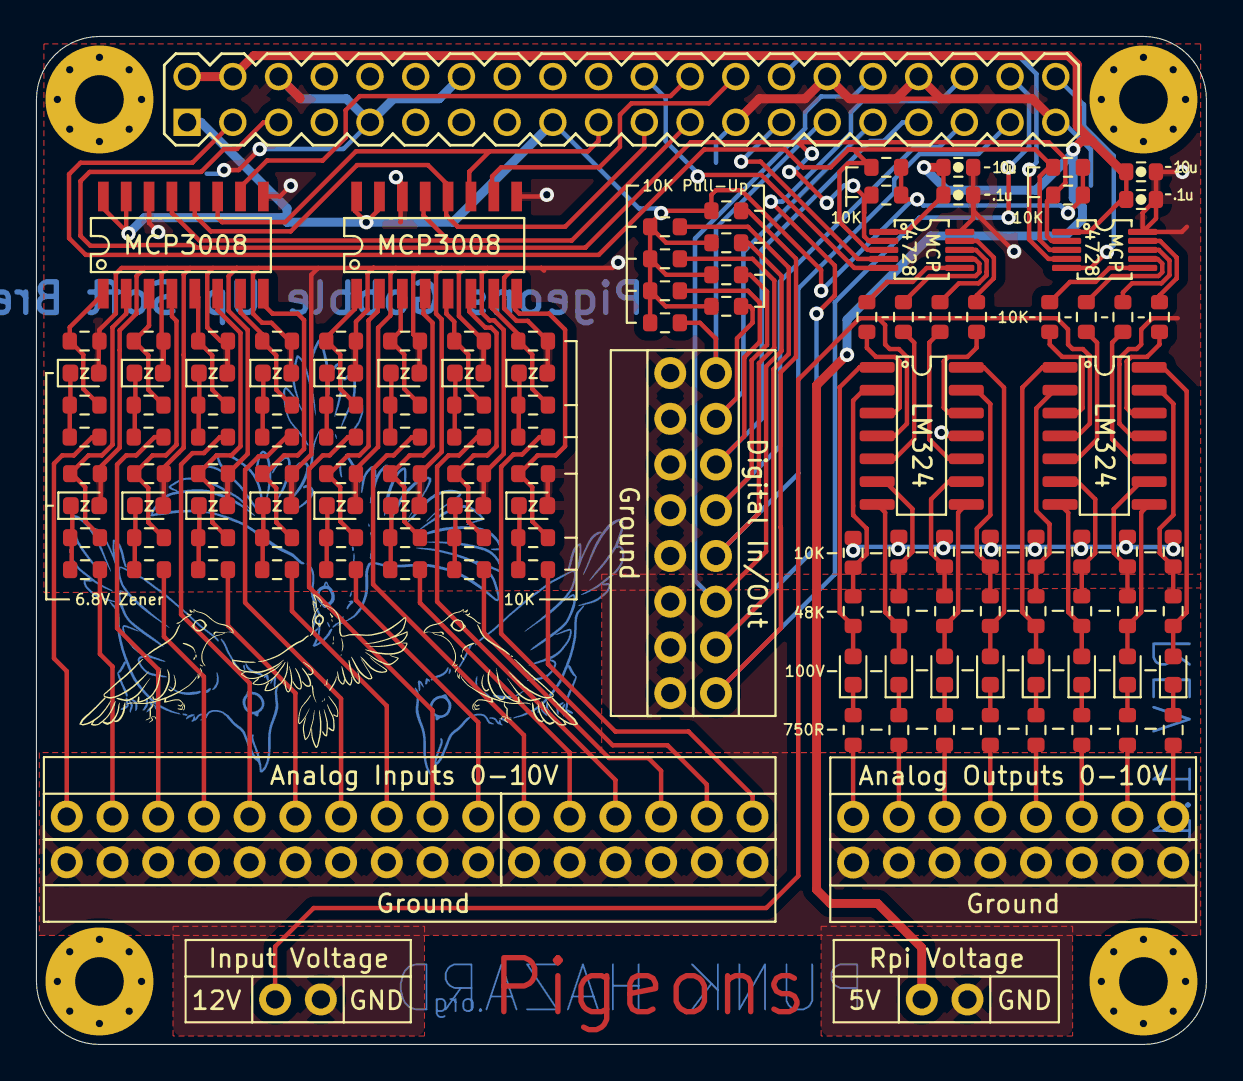
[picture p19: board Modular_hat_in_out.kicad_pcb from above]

Board: 2 copper layers, 65.0 x 56.0 mm, 141 parts (0 on the bottom side), 119 nets.

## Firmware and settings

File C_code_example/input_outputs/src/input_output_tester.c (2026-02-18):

#include <stdio.h>
#include <stdlib.h>
#include <string.h>
#include <spidev_lib.h>
#include <unistd.h>
#include <fcntl.h>
#include <linux/i2c-dev.h>
#include <sys/ioctl.h>
#include <linux/i2c.h>
#include <math.h>
#include <stdint.h>
#include <gpiod.h>
#include <errno.h>
#include <signal.h>

#define CHIP_NAME "gpiochip0"
#define CHIP_PATH "/dev/" CHIP_NAME

#define DAC_1 0x63
#define DAC_2 0x64

#define LDAC1_GPIO 0
#define LDAC2_GPIO 1

#define MCP4728_VREF_INTERNAL 1
#define MCP4728_GAIN_X1 0

#define DEFAULT_POINTS_PER_PERIOD 4096U
#define MIN_POINTS_PER_PERIOD 16U
#define MAX_POINTS_PER_PERIOD 20000U

#define DEFAULT_SAMPLE_DELAY_US 10U
#define MAX_SAMPLE_DELAY_US 1000000U

#define EQUALIZER_EVERY 20U
#define HISTORY_EVERY 100U

#define ADS_CHANNEL_COUNT 16
#define ADS_HISTORY_LINES 14
#define ADS_HISTORY_LINE_LEN 256

#define EQ_ROWS 5
#define EQ_STEPS_PER_ROW 8
#define EQ_BAR_WIDTH 4

typedef struct s_ldac_gpio_ctx {
    struct gpiod_chip *chip;
    struct gpiod_line_request *request;
    int ready;
}   t_ldac_gpio_ctx;

typedef struct s_ads_spi_ctx {
    int spi0_fd;
    int spi1_fd;
    int ready;
}   t_ads_spi_ctx;

static t_ldac_gpio_ctx g_ldac_ctx = {0};
static volatile sig_atomic_t g_keep_running = 1;

static void signal_handler(int signo)
{
    (void)signo;
    g_keep_running = 0;
}

static void delay_microseconds(unsigned int micros)
{
    usleep(micros);
}

static unsigned int parse_u32_or_default(const char *raw_value, const char *param_name,
    unsigned int default_value, unsigned int min_value, unsigned int max_value)
{
    char *end = NULL;
    unsigned long parsed;

    if (!raw_value || *raw_value == '\0') {
        printf("Warning: missing value for %s, using default %u\n", param_name, default_value);
        return default_value;
    }
    errno = 0;
    parsed = strtoul(raw_value, &end, 10);
    if (errno != 0 || end == raw_value || *end != '\0' || parsed < min_value || parsed > max_value) {
        printf("Warning: invalid %s='%s' (range %u..%u), using default %u\n",
            param_name, raw_value, min_value, max_value, default_value);
        return default_value;
    }
    return (unsigned int)parsed;
}

static int parse_runtime_options(int argc, char **argv,
    unsigned int *points_per_period, unsigned int *sample_delay_us)
{
    *points_per_period = DEFAULT_POINTS_PER_PERIOD;
    *sample_delay_us = DEFAULT_SAMPLE_DELAY_US;

    for (int i = 1; i < argc; i++) {
        if (strcmp(argv[i], "--help") == 0) {
            printf("Usage: %s [--resolution=<points>] [--delay-us=<microseconds>]\n", argv[0]);
            printf("  --resolution / --points : points per sine period (%u..%u), default: %u\n",
                MIN_POINTS_PER_PERIOD, MAX_POINTS_PER_PERIOD, DEFAULT_POINTS_PER_PERIOD);
            printf("  --delay-us              : delay between updates in microseconds (0..%u), default: %u\n",
                MAX_SAMPLE_DELAY_US, DEFAULT_SAMPLE_DELAY_US);
            printf("Display cadence is controlled by EQUALIZER_EVERY and HISTORY_EVERY defines in source.\n");
            return 1;
        } else if (strncmp(argv[i], "--resolution=", 13) == 0) {
            *points_per_period = parse_u32_or_default(argv[i] + 13, "resolution",
                DEFAULT_POINTS_PER_PERIOD, MIN_POINTS_PER_PERIOD, MAX_POINTS_PER_PERIOD);
        } else if (strncmp(argv[i], "--points=", 9) == 0) {
            *points_per_period = parse_u32_or_default(argv[i] + 9, "points",
                DEFAULT_POINTS_PER_PERIOD, MIN_POINTS_PER_PERIOD, MAX_POINTS_PER_PERIOD);
        } else if (strncmp(argv[i], "--delay-us=", 11) == 0) {
            *sample_delay_us = parse_u32_or_default(argv[i] + 11, "delay-us",
                DEFAULT_SAMPLE_DELAY_US, 0U, MAX_SAMPLE_DELAY_US);
        } else {
            printf("Warning: unknown option '%s' (use --help)\n", argv[i]);
        }
    }
    return 0;
}

static int i2c_init(const char *i2c_bus)
{
    int fd = open(i2c_bus, O_RDWR);
    if (fd < 0) {
        perror("Error opening I2C bus");
        return -1;
    }
    return fd;
}

static void scan_i2c_bus(int file)
{
    printf("\nScanning I2C bus...\n");
    printf("     0  1  2  3  4  5  6  7  8  9  A  B  C  D  E  F\n");

    for (int i = 0; i < 128; i += 16) {
        printf("%02x: ", i);
        for (int j = 0; j < 16; j++) {
            int addr = i + j;
            if (addr < 0x03 || addr > 0x77) {
                printf("   ");
                continue;
            }
            if (ioctl(file, I2C_SLAVE, addr) < 0) {
                printf("-- ");
                continue;
            }
            char buf;
            if (read(file, &buf, 1) < 0) {
                printf("-- ");
            } else {
                printf("%02x ", addr);
            }
        }
        printf("\n");
    }
    printf("\nScan completed.\n");
}

static void cleanup_ldac(void)
{
    if (g_ldac_ctx.request) {
        gpiod_line_request_release(g_ldac_ctx.request);
        g_ldac_ctx.request = NULL;
    }
    if (g_ldac_ctx.chip) {
        gpiod_chip_close(g_ldac_ctx.chip);
        g_ldac_ctx.chip = NULL;
    }
    g_ldac_ctx.ready = 0;
}

static int setup_ldac(void)
{
    struct gpiod_line_settings *line_settings = NULL;
    struct gpiod_line_config *line_config = NULL;
    struct gpiod_request_config *request_config = NULL;
    const unsigned int offsets[2] = {LDAC1_GPIO, LDAC2_GPIO};
    const enum gpiod_line_value init_values[2] = {
        GPIOD_LINE_VALUE_ACTIVE,
        GPIOD_LINE_VALUE_ACTIVE
    };

    g_ldac_ctx.chip = gpiod_chip_open(CHIP_PATH);
    if (!g_ldac_ctx.chip) {
        printf("Error: unable to open %s for LDAC control: %s\n", CHIP_PATH, strerror(errno));
        return -1;
    }

    line_settings = gpiod_line_settings_new();
    line_config = gpiod_line_config_new();
    request_config = gpiod_request_config_new();
    if (!line_settings || !line_config || !request_config) {
        printf("Error: unable to allocate libgpiod config objects\n");
        goto error;
    }

    if (gpiod_line_settings_set_direction(line_settings, GPIOD_LINE_DIRECTION_OUTPUT) < 0) {
        printf("Error: failed to configure LDAC lines as outputs\n");
        goto error;
    }
    if (gpiod_line_settings_set_output_value(line_settings, GPIOD_LINE_VALUE_ACTIVE) < 0) {
        printf("Error: failed to set initial LDAC output value\n");
        goto error;
    }
    if (gpiod_line_config_add_line_settings(line_config, offsets, 2, line_settings) < 0) {
        printf("Error: failed to add LDAC line settings\n");
        goto error;
    }
    if (gpiod_line_config_set_output_values(line_config, init_values, 2) < 0) {
        printf("Error: failed to set LDAC initial levels\n");
        goto error;
    }

    gpiod_request_config_set_consumer(request_config, "mcp4728-ldac");
    g_ldac_ctx.request = gpiod_chip_request_lines(g_ldac_ctx.chip, request_config, line_config);
    if (!g_ldac_ctx.request) {
        printf("Error: unable to request LDAC GPIO lines on %s: %s\n", CHIP_PATH, strerror(errno));
        goto error;
    }

    g_ldac_ctx.ready = 1;
    gpiod_request_config_free(request_config);
    gpiod_line_config_free(line_config);
    gpiod_line_settings_free(line_settings);
    return 0;

error:
    gpiod_request_config_free(request_config);
    gpiod_line_config_free(line_config);
    gpiod_line_settings_free(line_settings);
    cleanup_ldac();
    return -1;
}

static int ldac_pulse_low(unsigned int gpio_offset)
{
    if (!g_ldac_ctx.ready || !g_ldac_ctx.request) {
        return -1;
    }
    if (gpiod_line_request_set_value(g_ldac_ctx.request, gpio_offset, GPIOD_LINE_VALUE_ACTIVE) < 0) {
        return -1;
    }
    usleep(2);
    if (gpiod_line_request_set_value(g_ldac_ctx.request, gpio_offset, GPIOD_LINE_VALUE_INACTIVE) < 0) {
        return -1;
    }
    usleep(2);
    if (gpiod_line_request_set_value(g_ldac_ctx.request, gpio_offset, GPIOD_LINE_VALUE_ACTIVE) < 0) {
        return -1;
    }
    return 0;
}

static int mcp4728_write_channel_with_udac(int fd, uint8_t address, uint8_t channel,
    uint16_t value, uint8_t vref, uint8_t gain, uint8_t power_down, uint8_t udac)
{
    uint8_t buf[3];

    if (channel > 3 || value > 4095 || vref > 1 || gain > 1 || power_down > 3) {
        return -1;
    }

    buf[0] = (0x08 << 3) | ((channel & 0x03) << 1) | (udac & 0x01);
    buf[1] = ((vref & 0x01) << 7) | ((power_down & 0x03) << 5) | ((gain & 0x01) << 4) | ((value >> 8) & 0x0F);
    buf[2] = value & 0xFF;

    if (ioctl(fd, I2C_SLAVE, address) < 0) {
        return -1;
    }
    if (write(fd, buf, 3) != 3) {
        return -1;
    }
    return 0;
}

static int write_all_mcp_outputs(int i2c_fd, uint8_t udac, const uint16_t values[8])
{
    static const uint8_t addresses[2] = {DAC_1, DAC_2};

    for (int dac = 0; dac < 2; dac++) {
        for (int channel = 0; channel < 4; channel++) {
            int value_index = (dac * 4) + channel;
            if (mcp4728_write_channel_with_udac(i2c_fd, addresses[dac], (uint8_t)channel, values[value_index],
                    MCP4728_VREF_INTERNAL, MCP4728_GAIN_X1, 0, udac) != 0) {
                return -1;
            }
        }
    }
    return 0;
}

static int ads_spi_init(t_ads_spi_ctx *ctx)
{
    spi_config_t spi_config;

    memset(ctx, 0, sizeof(*ctx));
    spi_config.mode = 0;
    spi_config.speed = 1000000;
    spi_config.delay = 0;
    spi_config.bits_per_word = 8;

    ctx->spi0_fd = spi_open("/dev/spidev0.0", spi_config);
    if (ctx->spi0_fd < 0) {
        printf("Error: /dev/spidev0.0 unavailable\n");
        return -1;
    }
    ctx->spi1_fd = spi_open("/dev/spidev0.1", spi_config);
    if (ctx->spi1_fd < 0) {
        printf("Error: /dev/spidev0.1 unavailable\n");
        spi_close(ctx->spi0_fd);
        ctx->spi0_fd = -1;
        return -1;
    }
    ctx->ready = 1;
    return 0;
}

static void ads_spi_cleanup(t_ads_spi_ctx *ctx)
{
    if (ctx->spi0_fd >= 0) {
        spi_close(ctx->spi0_fd);
        ctx->spi0_fd = -1;
    }
    if (ctx->spi1_fd >= 0) {
        spi_close(ctx->spi1_fd);
        ctx->spi1_fd = -1;
    }
    ctx->ready = 0;
}

static int ads_read_voltage(t_ads_spi_ctx *ctx, uint8_t channel, float *voltage_value)
{
    uint8_t tx_buffer[3] = {0};
    uint8_t rx_buffer[3] = {0};
    uint8_t local_channel;
    int spifd;

    if (!ctx->ready || channel > 15 || !voltage_value) {
        return -1;
    }

    spifd = (channel < 8) ? ctx->spi0_fd : ctx->spi1_fd;
    local_channel = (channel < 8) ? channel : (uint8_t)(channel - 8);

    tx_buffer[0] = 1;
    tx_buffer[1] = (uint8_t)((8 + local_channel) << 4);
    tx_buffer[2] = 0;

    if (spi_xfer(spifd, tx_buffer, 3, rx_buffer, 3) < 0) {
        return -1;
    }

    *voltage_value = (float)(((rx_buffer[1] & 3) << 8) + rx_buffer[2]) / 1023.0f * 9.9f;
    return 0;
}

static void ads_capture_snapshot(t_ads_spi_ctx *ads_ctx, float voltages[ADS_CHANNEL_COUNT],
    uint8_t valid[ADS_CHANNEL_COUNT])
{
    for (uint8_t ch = 0; ch < ADS_CHANNEL_COUNT; ch++) {
        voltages[ch] = 0.0f;
        valid[ch] = 0;
        if (ads_read_voltage(ads_ctx, ch, &voltages[ch]) == 0) {
            valid[ch] = 1;
        }
    }
}

static void ads_build_history_line(char *line, size_t line_size, unsigned long sample_counter,
    const float voltages[ADS_CHANNEL_COUNT], const uint8_t valid[ADS_CHANNEL_COUNT])
{
    int used = snprintf(line, line_size, "#%08lu", sample_counter);
    if (used < 0 || (size_t)used >= line_size) {
        return;
    }
    for (uint8_t ch = 0; ch < ADS_CHANNEL_COUNT; ch++) {
        int written;
        if (valid[ch]) {
            // 1 leading space + 4 chars value so it aligns with 4-char equalizer bars.
            written = snprintf(line + used, line_size - (size_t)used, " %4.1f", voltages[ch]);
        } else {
            written = snprintf(line + used, line_size - (size_t)used, " ERR ");
        }
        if (written < 0 || (size_t)written >= line_size - (size_t)used) {
            break;
        }
        used += written;
    }
}

static void ads_push_history(char history[ADS_HISTORY_LINES][ADS_HISTORY_LINE_LEN],
    unsigned int *history_count, const char *line)
{
    if (*history_count < ADS_HISTORY_LINES) {
        snprintf(history[*history_count], ADS_HISTORY_LINE_LEN, "%s", line);
        (*history_count)++;
        return;
    }

    for (unsigned int i = 1; i < ADS_HISTORY_LINES; i++) {
        snprintf(history[i - 1], ADS_HISTORY_LINE_LEN, "%s", history[i]);
    }
    snprintf(history[ADS_HISTORY_LINES - 1], ADS_HISTORY_LINE_LEN, "%s", line);
}

static int voltage_to_equalizer_steps(float voltage)
{
    double scaled;

    if (voltage < 0.0f) {
        voltage = 0.0f;
    } else if (voltage > 10.0f) {
        voltage = 10.0f;
    }

    scaled = ((double)voltage / 10.0) * (double)(EQ_ROWS * EQ_STEPS_PER_ROW);
    return (int)lround(scaled);
}

static void ads_render_dashboard(const char history[ADS_HISTORY_LINES][ADS_HISTORY_LINE_LEN],
    unsigned int history_count, const float voltages[ADS_CHANNEL_COUNT], const uint8_t valid[ADS_CHANNEL_COUNT],
    unsigned int points_per_period, unsigned int sample_delay_us)
{
    static const char *blocks[EQ_STEPS_PER_ROW + 1] = {" ", "▁", "▂", "▃", "▄", "▅", "▆", "▇", "█"};

    // Keep an always-updated dashboard: history above, equalizer on the last 5 lines.
    printf("\033[H\033[J");
    printf("=== MCP->ADS loopback test ===\n");
    printf("Config: resolution=%u points | delay=%u us | eq-every=%u | history-every=%u\n",
        points_per_period, sample_delay_us, EQUALIZER_EVERY, HISTORY_EVERY);
    printf("ADS voltage history (V):\n");
    for (unsigned int i = 0; i < history_count; i++) {
        printf("%s\n", history[i]);
    }
    for (int row = EQ_ROWS - 1; row >= 0; row--) {
        // Prefix width is fixed to 9 chars to match history line prefix (#00000000).
        printf("%2dV%6s", (row + 1) * 2, "");
        for (uint8_t ch = 0; ch < ADS_CHANNEL_COUNT; ch++) {
            int steps = valid[ch] ? voltage_to_equalizer_steps(voltages[ch]) : 0;
            int cell = steps - (row * EQ_STEPS_PER_ROW);

            if (cell < 0) {
                cell = 0;
            } else if (cell > EQ_STEPS_PER_ROW) {
                cell = EQ_STEPS_PER_ROW;
            }
            printf(" ");
            for (int w = 0; w < EQ_BAR_WIDTH; w++) {
                printf("%s", blocks[cell]);
            }
        }
        printf("\n");
    }
    printf("%9s", "");
    for (uint8_t ch = 0; ch < ADS_CHANNEL_COUNT; ch++) {
        printf(" %4u", ch);
    }
    printf("\n");
    fflush(stdout);
}

int main(int argc, char **argv)
{
    const char *i2c_bus = "/dev/i2c-1";
    const double two_pi = 2.0 * 3.14159265358979323846;
    const double phase_step = two_pi / 8.0;
    unsigned int points_per_period;
    unsigned int sample_delay_us;
    int i2c_fd;
    int ldac_ready;
    int ldac_error_reported = 0;
    unsigned long sample_counter = 0;
    char ads_history[ADS_HISTORY_LINES][ADS_HISTORY_LINE_LEN] = {{0}};
    unsigned int ads_history_count = 0;
    char history_line[ADS_HISTORY_LINE_LEN] = {0};
    float ads_voltages[ADS_CHANNEL_COUNT] = {0.0f};
    uint8_t ads_valid[ADS_CHANNEL_COUNT] = {0};
    t_ads_spi_ctx ads_ctx;
    int parse_status;

    parse_status = parse_runtime_options(argc, argv, &points_per_period, &sample_delay_us);
    if (parse_status > 0) {
        return 0;
    }

    signal(SIGINT, signal_handler);
    signal(SIGTERM, signal_handler);

    i2c_fd = i2c_init(i2c_bus);
    if (i2c_fd < 0) {
        return 1;
    }

    if (ads_spi_init(&ads_ctx) != 0) {
        close(i2c_fd);
        return 1;
    }

    scan_i2c_bus(i2c_fd);
    ldac_ready = (setup_ldac() == 0);
    if (!ldac_ready) {
        printf("Warning: LDAC init failed, fallback to immediate updates (UDAC=0).\n");
    }

    while (g_keep_running) {
        for (unsigned int i = 0; i < points_per_period && g_keep_running; i++) {
            uint16_t phased_values[8];
            uint8_t udac = ldac_ready ? 1 : 0;
            double angle = two_pi * (double)i / (double)points_per_period;

            for (int output = 0; output < 8; output++) {
                double shifted_angle = angle + ((double)output * phase_step);
                phased_values[output] = (uint16_t)(2048.0 + 2047.0 * sin(shifted_angle));
            }

            if (write_all_mcp_outputs(i2c_fd, udac, phased_values) != 0) {
                printf("Error: failed to write MCP4728 outputs\n");
                g_keep_running = 0;
                break;
            }

            if (ldac_ready) {
                if (ldac_pulse_low(LDAC1_GPIO) < 0 || ldac_pulse_low(LDAC2_GPIO) < 0) {
                    ldac_ready = 0;
                    if (!ldac_error_reported) {
                        printf("Warning: LDAC pulse failed, switching to immediate updates (UDAC=0).\n");
                        ldac_error_reported = 1;
                    }
                }
            }

            if ((sample_counter % EQUALIZER_EVERY) == 0) {
                ads_capture_snapshot(&ads_ctx, ads_voltages, ads_valid);
                if ((sample_counter % HISTORY_EVERY) == 0) {
                    ads_build_history_line(history_line, sizeof(history_line), sample_counter, ads_voltages, ads_valid);
                    ads_push_history(ads_history, &ads_history_count, history_line);
                }
                ads_render_dashboard(ads_history, ads_history_count, ads_voltages, ads_valid,
                    points_per_period, sample_delay_us);
            }

            sample_counter++;
            delay_microseconds(sample_delay_us);
        }
    }

    ads_spi_cleanup(&ads_ctx);
    cleanup_ldac();
    close(i2c_fd);
    printf("Stopped.\n");
    return 0;
}

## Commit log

2023-11-15 [UDPT] Project name
    [Modular_hat_in_out.kicad_pcb, Modular_hat_in_out.kicad_sch, Modular_hat_in_out.sch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]
2023-11-15 [UDPT] MCP3008 & LM324 & MCP4728
    [Modular_hat_in_out.kicad_sch]
2023-11-15 [UDPT] MCP3008 in schematics
    [Modular_hat_in_out.kicad_sch]
2023-11-15 [ADD] Connections and update configuration resistors
    [Modular_hat_in_out.kicad_sch]
2023-11-15 [ADD] Update design and Schematics for 4 channels DAC seems OK
    [Modular_hat_in_out.kicad_sch, outputProtection.kicad_sch]
2023-11-27 [UDPT] Mounting Holes Upgraded
    [Modular_hat_in_out.kicad_pcb]
2023-12-13 [ADD] Schematics in progress
    [Modular_hat_in_out.kicad_sch, outputProtection.kicad_sch]
2023-12-14 [ERC] Major problems fixed
    [Modular_hat_in_out.kicad_sch, inputRegulator.kicad_sch]
2023-12-15 [UDPT] Electrical design
    [Modular_hat_in_out.kicad_sch]
2024-07-27 [ADD] Update to last kicad version
    [Modular_hat_in_out.kicad_sch, inputRegulator.kicad_sch, outputProtection.kicad_sch]
2024-07-27 [ADD] MCP4728 footprint
2024-07-27 [ADD] Footprints
    [Modular_hat_in_out.kicad_sch, inputRegulator.kicad_sch, outputProtection.kicad_sch]
2024-07-27 [ADD] LCSC Capacitor parts
    [Modular_hat_in_out.kicad_sch]
2024-07-27 [ADD] ML324 footprint
    [Modular_hat_in_out.kicad_pcb, Modular_hat_in_out.kicad_sch]
2024-07-27 [CLEAN] PCB Editor
    [Modular_hat_in_out.kicad_pcb]
2024-07-27 [ADD] MCP3008 preplacement
    [Modular_hat_in_out.kicad_pcb]
2024-07-27 [ADD] LM324 preplacement
    [Modular_hat_in_out.kicad_pcb]
2024-07-28 [ADD] Routing LM324
    [Modular_hat_in_out.kicad_pcb]
2024-07-28 [ADD] Routing MCP4728
    [Modular_hat_in_out.kicad_pcb]
2024-07-28 [ADD] Some placements
    [Modular_hat_in_out.kicad_pcb]
2024-07-28 [ADD] Pre routing MCP3008
    [Modular_hat_in_out.kicad_pcb]
2024-07-28 [ADD] Digital routing
    [Modular_hat_in_out.kicad_pcb]
2024-07-28 [ADD] Routing digital
    [Modular_hat_in_out.kicad_pcb]
2024-07-29 [ADD] 12V input in shematics
    [Modular_hat_in_out.kicad_pcb, Modular_hat_in_out.kicad_sch, outputProtection.kicad_sch]
2024-07-29 [ADD] All components routed
    [Modular_hat_in_out.kicad_pcb, Modular_hat_in_out.kicad_sch]
2024-07-29 [ADD] Some routing
    [Modular_hat_in_out.kicad_pcb]
2024-07-29 [ADD] Some GND routing
    [Modular_hat_in_out.kicad_pcb]
2024-07-29 [ADD] ERC & DRC OK
    [Modular_hat_in_out.kicad_pcb]
2024-07-29 [ADD] Some Silkcreen
    [Modular_hat_in_out.kicad_pcb]
2024-07-29 [ADD] Some pigeons
    [Modular_hat_in_out.kicad_pcb]
2024-07-29 [ADD] Somes pigeons
    [Modular_hat_in_out.kicad_pcb]
2024-07-29 [ADD] 2 Metalic pigeons
    [Modular_hat_in_out.kicad_pcb]
2024-07-29 [ADD] One more metalic pigeon
    [Modular_hat_in_out.kicad_pcb]
2024-07-29 [ADD] Pigeon citation
    [Modular_hat_in_out.kicad_pcb]
2024-07-30 [ADD] Some plants
    [Modular_hat_in_out.kicad_pcb]
2024-08-06 [ADD] Some drawings
    [Modular_hat_in_out.kicad_pcb]
2024-08-07 [UDPT] Mac se logo
    [bom.csv, designators.csv, positions.csv]
2024-08-21 [ADD] Build for production
    [Modular_hat_in_out.kicad_pcb, Modular_hat_in_out.kicad_sch, bom.csv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]
2024-08-21 [ADD] Schematics PDF
2024-08-21 [ADD] Revision number (1.0)
    [Modular_hat_in_out.kicad_pcb, Modular_hat_in_out.kicad_sch, designators.csv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]
2024-08-21 [CLEAN] Build
    [bom.csv, designators.csv, positions.csv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]
2024-08-22 [UPDT] Silkscreen on some footprints
    [Modular_hat_in_out.kicad_pcb, bom.csv, positions.csv]
2024-08-22 [FIX] Update from schematics warning
    [Modular_hat_in_out.kicad_pcb, Modular_hat_in_out.kicad_sch, bom.csv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]
2025-01-27 [ADD] less buggy code
    [analog_input_reader.c]
2025-10-28 [ADD] 5V Input voltage in schematics + clean
    [Modular_hat_in_out.kicad_pcb, Modular_hat_in_out.kicad_sch, inputRegulator.kicad_sch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]
2025-10-28 [ADD] New Revision 1.1
    [Modular_hat_in_out.kicad_pcb, Modular_hat_in_out.kicad_sch, designators.csv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]
2026-02-18 [FIX] Analog outputs code
    [analog_input_reader.c]
